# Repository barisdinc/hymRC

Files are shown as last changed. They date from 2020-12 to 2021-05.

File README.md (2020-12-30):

Bu projenin amaci role olarak kullanilmak uzere hazirlanan duzeneklerin kontrolunu saglamak ve bu sistemin uzaktan kumandasi ile tanitim bilgilerini olusturacak bir kart tasarimi yapmaktir.

Bu proje **_TA7OM Hudaverdi Gunes_**'in tesviki ile baslatilmistir. Mevcutta yillar once yaptigimiz ve pek cok rolede kullanilan genelde PIC tabanli Role Kontrol kartlarinin daha modern hale getirilmesi hedeflenecektir.

Aklimizdaki ozellikler asagidaki gibidir;

### Temel Ozellikler
1. Islemci unitesi olarak PIC yerine kolay erisilebilir ve programlanabilir ATMEL (Arduino) tercih edilecektir
1. 12 Volt ile beslenecektir
1. Role kontrol ozellikleri olacaktir
1. Durum gosterimi icin LED bulunacaktir
1. Dis arayuz baglantilari optokupler veya roleler uzerinden yapilacaktir
1. COR/CAS destegi olmalidir
1. COR/CAS destegi +/- olabilmelidir
1. Ayarlarin gosterimi icin LCD bulunacaktir (opsiyonel)
1. Ayarlarin goruntulenmesi/degistirilmesi icin rotary encoder bulunacaktir (opsiyonel)
1. Sistem icinde gercek zaman saati bulunacaktir (opsiyonel)
1. Roleye simplex Link sistemi ilave edilebilmelidir
  * Link COR girişi olmalı
  * Ancak Link girişinden sinyal geldiğinde Role de Kuyruk süresi olmamalı
  * İki VHF cihaz ile yapılan Role bir birine UHF üzerinden ücüncü cihaz ile Linkli olsun. 
  * iki cihazdan yapılan VHF Role Normal aktivtesini sürdürürken Kullanıcı Mandalı attığında Role göndermede iken aynı zamanda UHF link cihazı da göndermeye geçmelidir. 
  * Kullanıcı Mandalı bıraktığında Role Kuruk süresi sonrasında kapanacak ancak Link ise hiçbir gecikme olmadan, yani kuyruk süresi olmadan anında kapanacak. Bunun amacı Link üzerinden gelen sinyal zaten bir rokleden gelmekte olup, üzerinde kuyruk süresi vardır. 
  * ikinci bir kuyruk süresine ihtiyaç yoktur.
1. ...

### Role KOntrol Ozellikleri
1. Squelch/Sinyal girisi
1. Otomatik enterferans engelleme
1. ... 

### Uzaktan Kumanda Ozellikleri
1. DTMF ile uzaktan kumanda ozelligi olacaktir
1. Role acma/kapatma
1. Ton acma/kapatma
1. Morse tanitim acma/kapatma
1. AX25 tanitim acma/kapatma
1. belirlenen sure boyunca kapali kalma
1. Otomatik enterferans engelleme acma/kapama
1. Link acma/kapama
1. Kuyruk suresi ayari (uzun/orta/kisa)
1. Fan/Role acma/kapatma
1. AX25 ile uzaktan ayar yuklenmesi yapilabilecektir (opsiyonel)
1. SSTV Goruntusu iste (opsiyonel)
1. ...

### Tanitim Bilgisi
1. Beacon Tanitim ozelligi bulunacaktir (Orn: YM7KO 88.5 KN80WU 5W -10C 138V 121220 1919)
  * Morse olarak istasyon tanitimi basacaktir
  * Morse tanitim icinde asagidaki bilgiler olacaktir
  * Ton bilgisi
  * Lokasyon bilgisi (grid   square)
  * Cikis Gucu
  * Ortam sicakligi
  * Aku voltajlari
  * Tarih ve saat (gercek zamani opsiyonu durumunda
  * ...
  
1. Uzaktan kumanda sifre kontrollu olacaktir
  * Sifre uzaktan degistirilebilecektir
  * Sifre tanimli bir sifre kumesinden (Orn: 10 degisik sifre) sirayla degisecektir, aktif sifre no sorgulanabilecektir
  * ...
  
1. Beacon sinyali AX25 olarak da gonderilecektir
  * AX25 beacon sinyali icinde rolenin tum ayarlarinin aktif durumu bulunabilecektir
  * ...

**NOT:** Liste ilgili goruslerinizi ve eklenmesini istediginiz ozellikleri ISSUE bolumunden veya email ile bize bildiriniz. (barisdinc###gmail.com)

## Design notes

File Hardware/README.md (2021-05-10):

This folder will contain Schematic and PCB versions for different repeater application options

PCBs arrived...
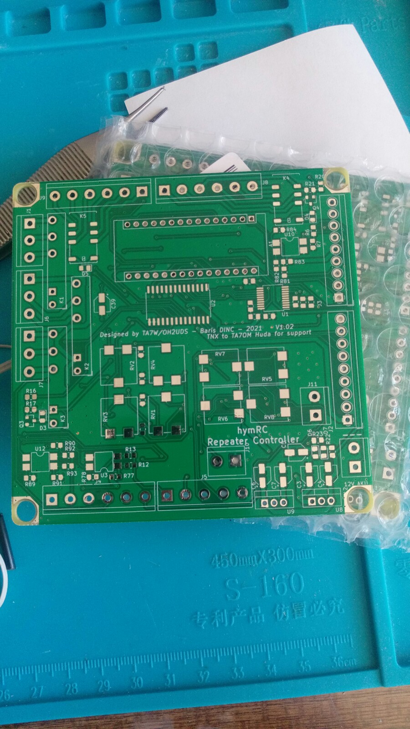
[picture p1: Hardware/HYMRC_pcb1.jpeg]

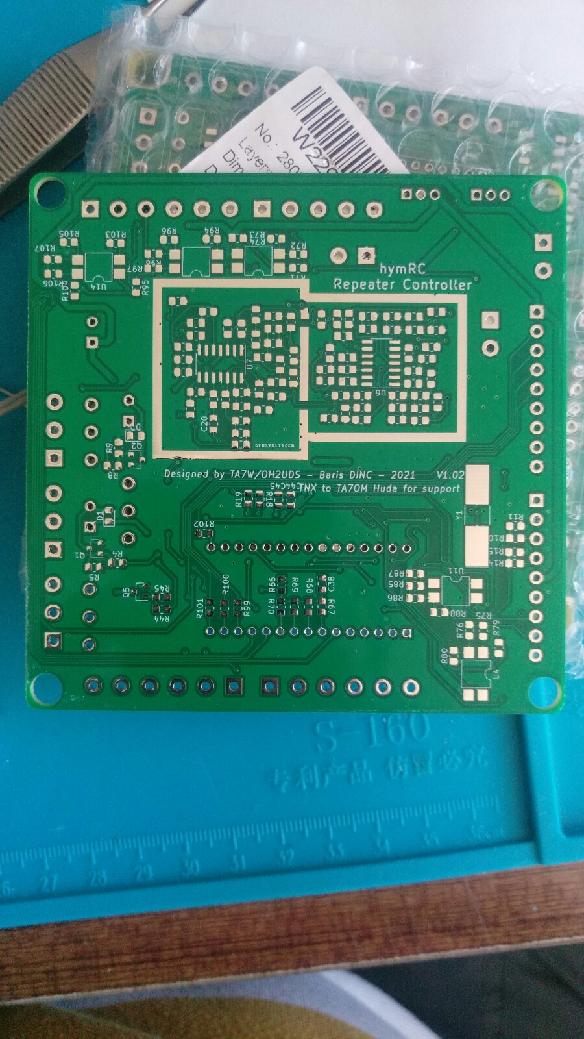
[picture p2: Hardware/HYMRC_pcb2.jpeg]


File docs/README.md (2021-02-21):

Atmega328p uzerinde 14 adet digital ve 8 adet analog pine sahiptir. BU pinlerden bazilari ozel amaclar icin peripherallere baglidir (Orn: seri, I2C, SPI veya PWM)

# Pin eslemeleri :
## Digital pinler
### Seri Data
Role kontrolcusunu ilerde baska bir sistemler bhaberlestirme ihtiyaci dogrudugune bu pinler seri haberlesme amaciyla kullanilacaktir
* D0 Seri iletisim icin kullanilacak (RX)
* D1 Seri iletisim icin kullanilacak (TX)

### interrupt (kesme) gerektiren islemler icin
* D2 KS8870 StD (interrupt)
* D3 Squelch input icin interrupt (ya da daha hizli bir is icin)

###TOne Decoder baglantisi (4+1 Pin)

* D4 MT8870 Q1
* D5 MT8870 Q2
* D6 MT8870 Q3
* D7 MT8870 Q4

### Mors ve data uretme
* ???? PWM cikisi olarak kullanialcak

### Acma kapama isleri
* D8 PTT kontrol
* D9 Role veya Digital  KOntrol 1

### Harici veriyolu (sensorler vb icin SPI)
* D10 SPI ihtiyaci icin kullanialcak (SS)
* D11 SPI ihtiyaci icin kullanialcak (MOSI)
* D12 SPI ihtiyaci icin kullanialcak (MISO)
* D13 SPI ihtiyaci icin kullanialcak (SCK)

## Analog Okuyucular
### Algilayicilar
* A0 Aku Durumu
* A1 Analog Sensor 1 (ornek: sicaklik, isik durumu, ruzgar)
* A2 Analog Sensor 2 (ornek: sicaklik, isik durumu, ruzgar)

* A3 BOS (AX25 dinleme icin kullanilabilir)

### Harici veriyolu (sensorler vb icin I2C)
* A4 I2C iletisim icin kullanilacak (SDA)
* A5 I2C iletisim icin kullanilacak (SCL)

* A6 BOS
* A7 BOS

Onemli Not:
-----------
* Rolenin mors ciktisina ek olarak AX25 paket radyo verisi olusturmak icin en az 4 pin ayristirilmasi gerekebilir ya da harici bir DAC chip kullanilabilir
* Rolenin AX25 alma islemi yapabilmesi icin analog portlardan birinin bu ise ayrilmasi gerekebilir

### Test Devresi
## MT3170 / KT8870 Bacak Baglantilari
Piyasada en kolay bulunan versiyonu 18 bacakli hali olup eger benim gibi kazara 20 bacakli versiyonunu kullaniyorsaniz internette cok kolay bulunamayan bacak baglanti detaylari asagidaki gibidir;

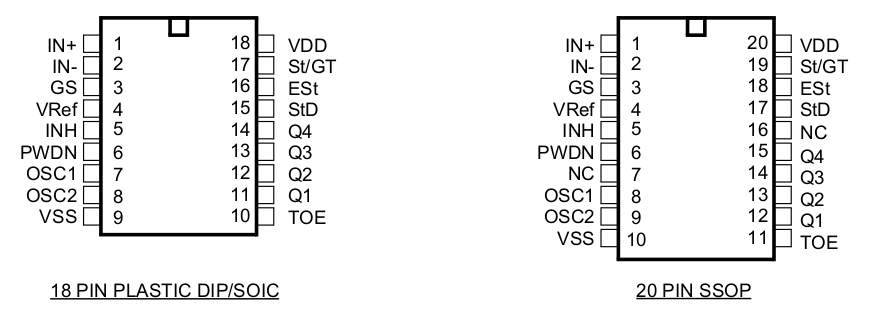
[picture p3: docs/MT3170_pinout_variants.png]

  
Ilk ornek uygulamamda asagidaki gibi bir devreyi kucuk bir protoboard uzerine kurup calismaya basladim;
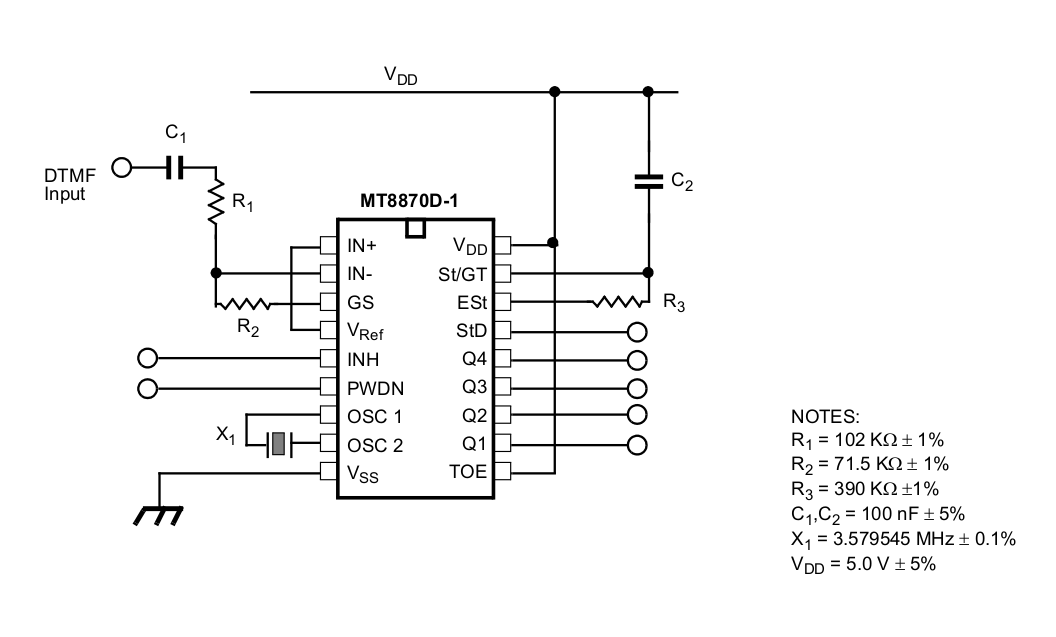
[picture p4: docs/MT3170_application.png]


Kurulu hali gorunumu

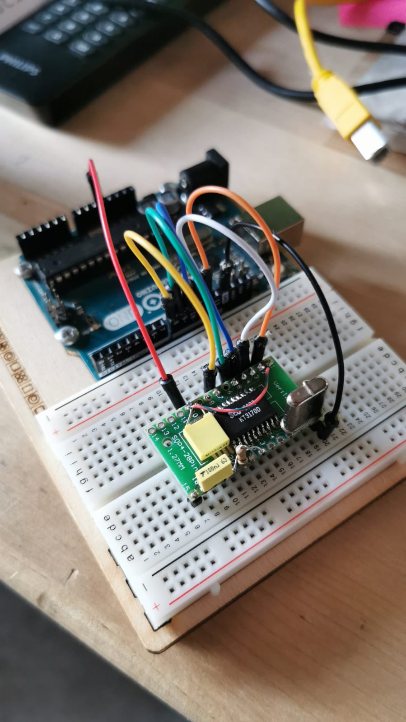
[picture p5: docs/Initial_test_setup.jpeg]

  
## 16 Bit port genisletici kullanimi
 
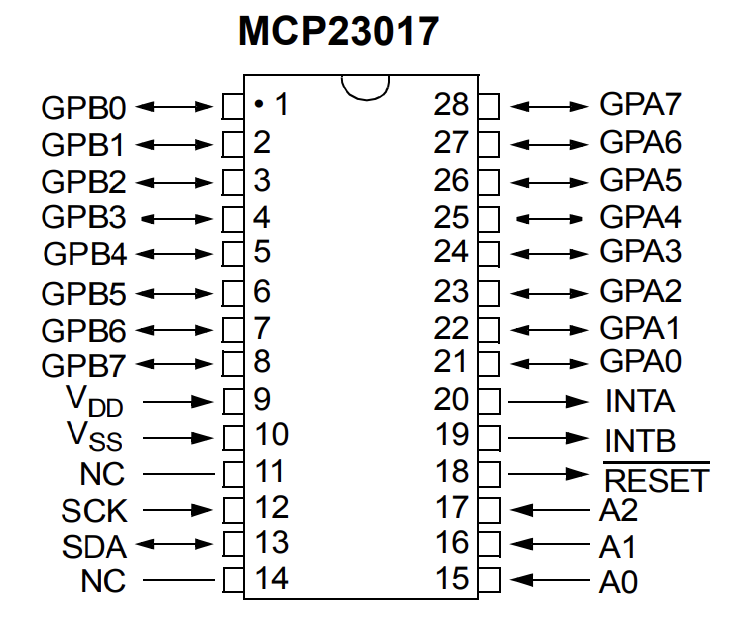
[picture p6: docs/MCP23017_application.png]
 
  
 * A0
 * A1
 * A2
 * A3
 * A4
 * A5
 * A6
 * A7
 * A8
  
 * B0 MT8870 Q1       (input) Interrupt On Pin
 * B1 MT8870 Q2       (input) Interrupt On Pin
 * B2 MT8870 Q3       (input) Interrupt On Pin
 * B3 MT8870 Q4       (input) Interrupt On Pin
 * B4 MT8870 StD      (input) Interrupt On Change 
 * B5 General Purpose (input) No Interrupt
 * B6 General Purpose (input) No Interrupt
 * B7 General Purpose (input) No Interrupt
  
 * INTA -> Pin 2 of MCU (INT0)
 * INTB -> Pin 3 of MCU (INT1)

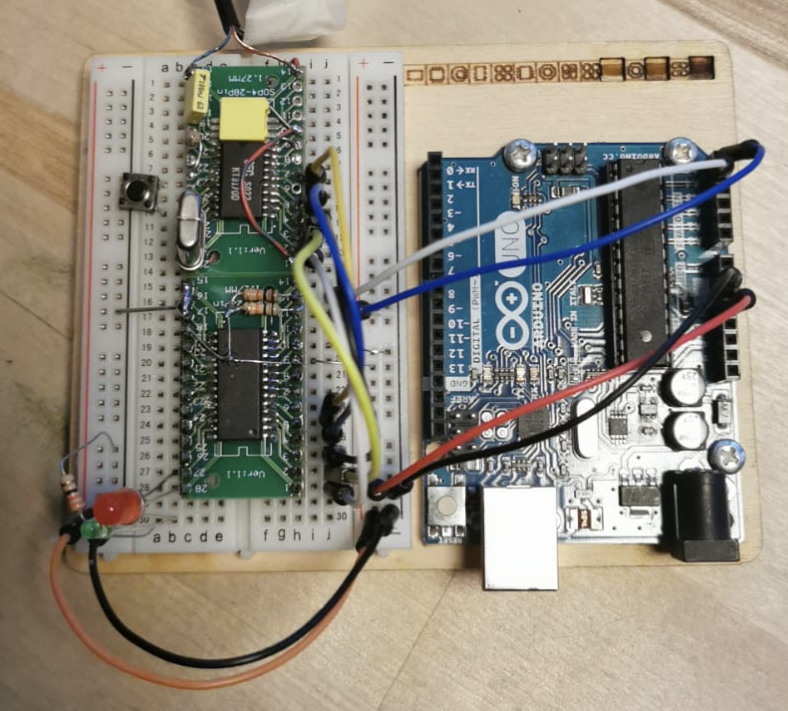
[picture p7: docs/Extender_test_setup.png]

  
## Initial Version Of Schematic
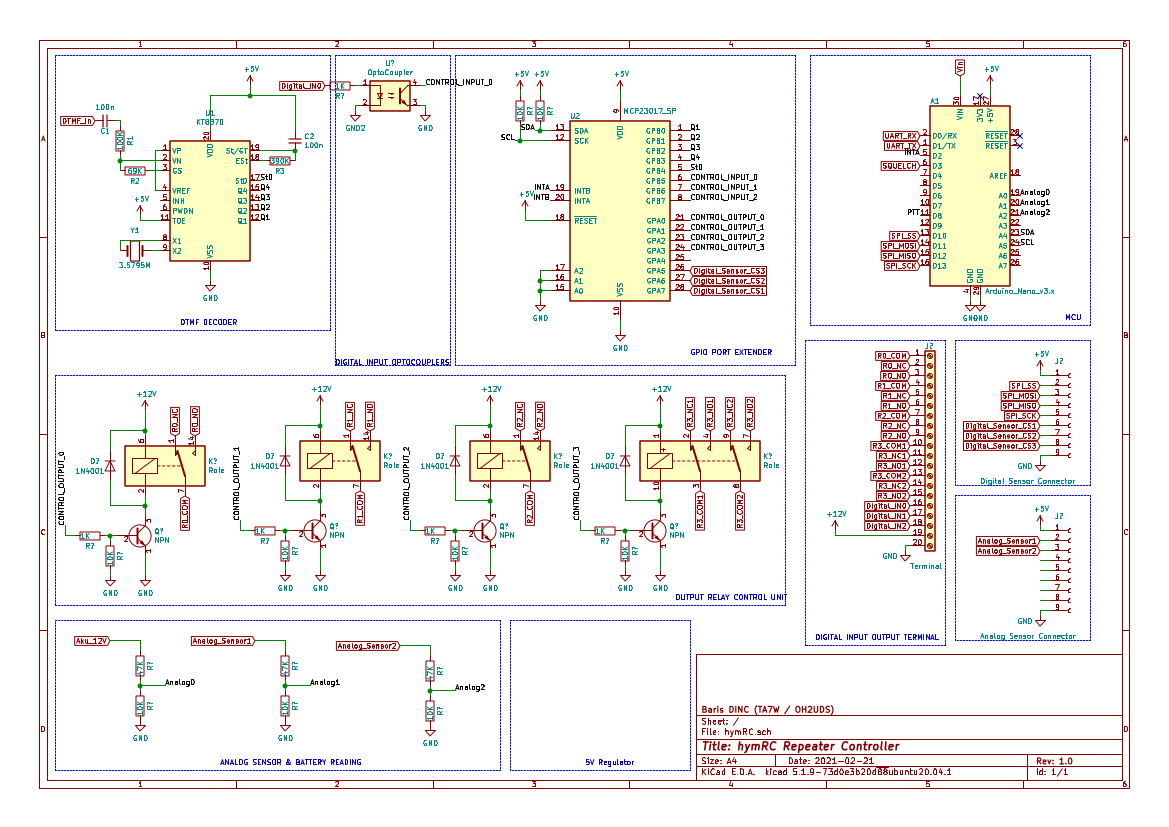
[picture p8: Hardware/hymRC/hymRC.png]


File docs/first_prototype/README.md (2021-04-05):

this is first prototype 3D views of KiCAD files....

#Front View:
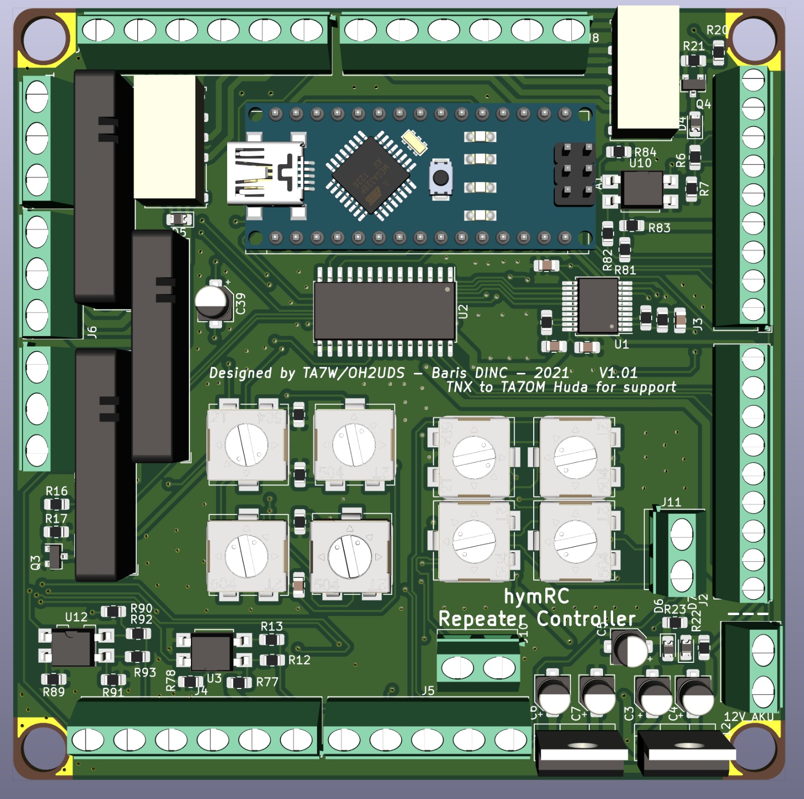
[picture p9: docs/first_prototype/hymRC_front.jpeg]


#Back View:
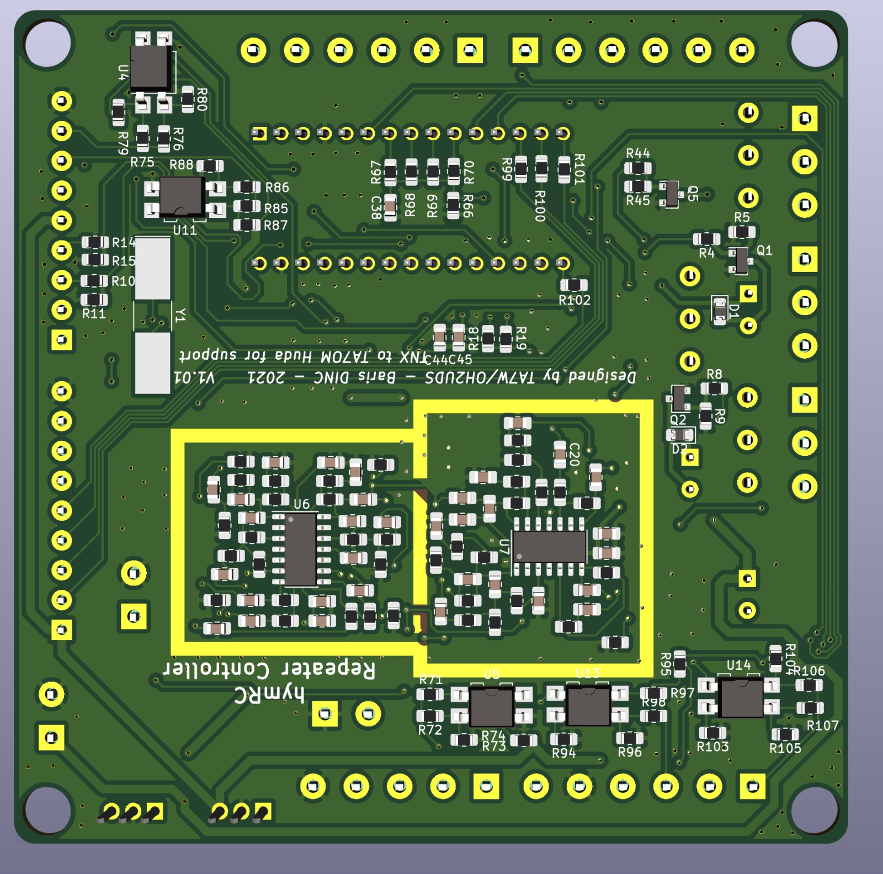
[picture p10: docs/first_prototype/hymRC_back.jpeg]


#Angle View:
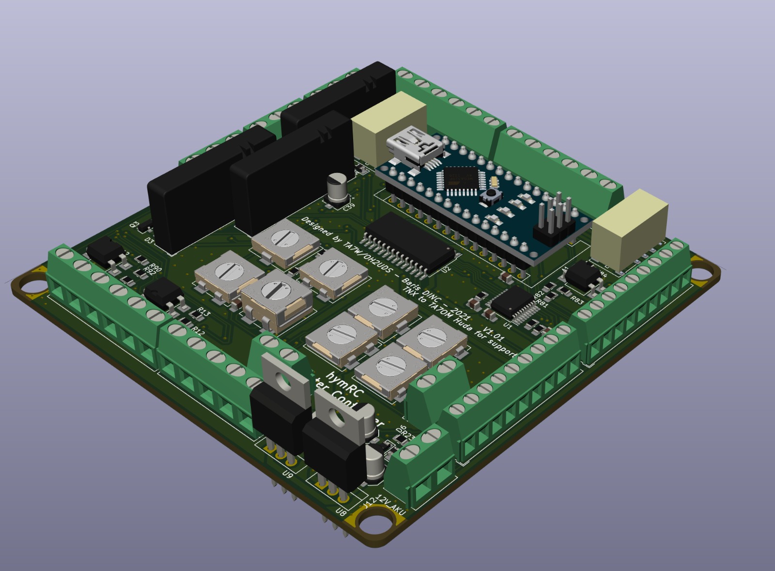
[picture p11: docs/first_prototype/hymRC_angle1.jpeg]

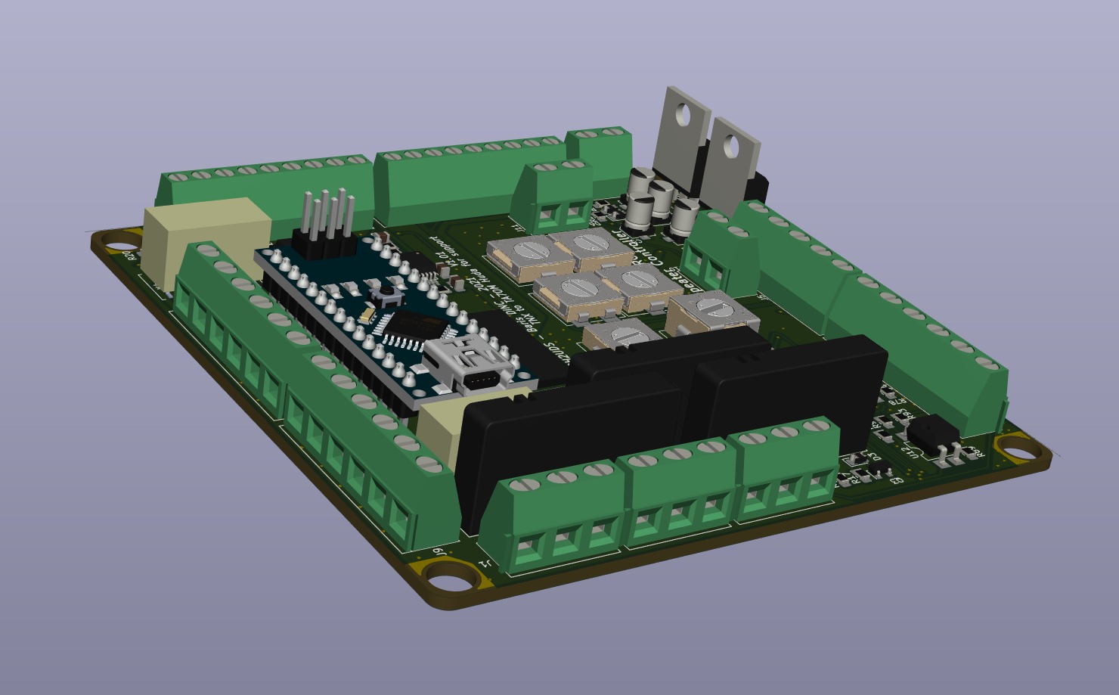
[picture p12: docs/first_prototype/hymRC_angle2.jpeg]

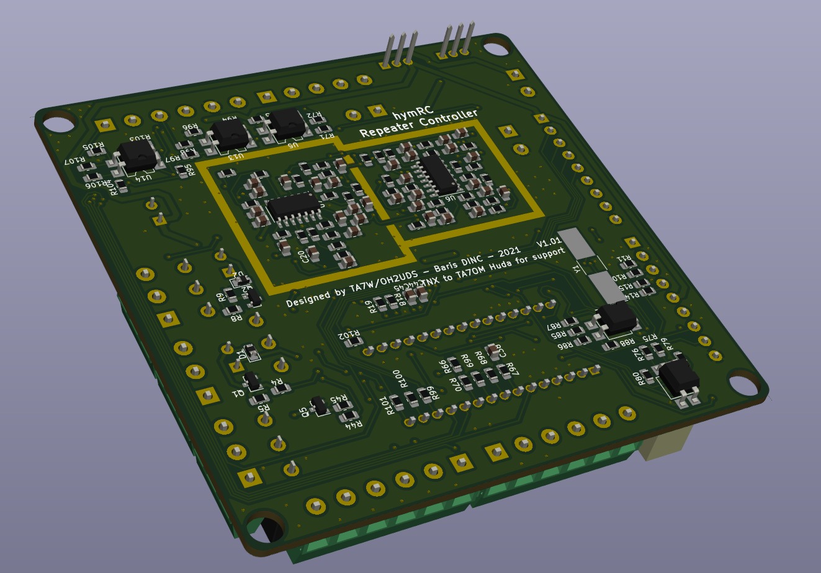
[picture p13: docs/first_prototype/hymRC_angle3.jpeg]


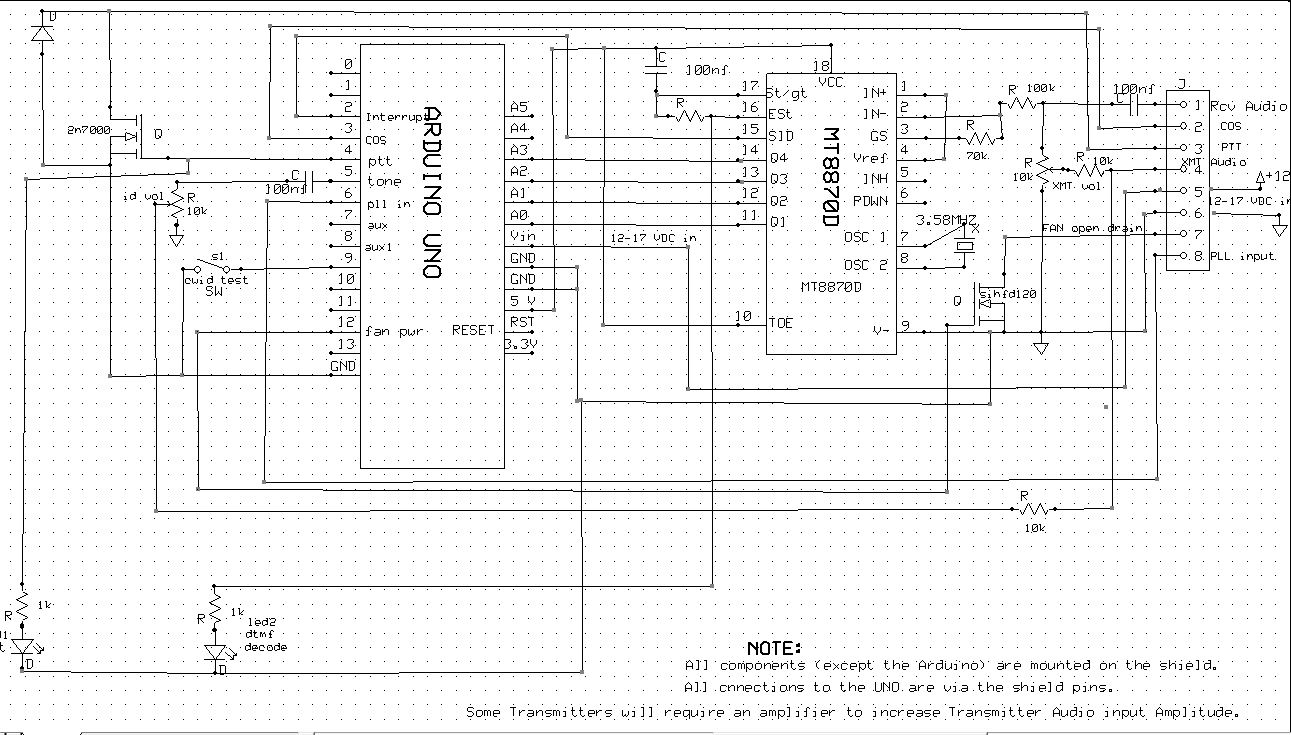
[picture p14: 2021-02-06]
Research/Rpt w_DTMF schematic.JPG

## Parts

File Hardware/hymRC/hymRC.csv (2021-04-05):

Id | Designator | Package | Quantity | Designation | Supplier and ref
1 | Y1 | Crystal_SMD_SeikoEpson_MC405-2Pin_9.6x4.1mm_HandSoldering | 1 | 3.5795M
2 | U14,U13,U12,U11,U10,U5,U4,U3 | SMDIP-4_W7.62mm | 8 | OptoCoupler
3 | U9 | TO-220-3_Vertical | 1 | L7805
4 | U8 | TO-220-3_Vertical | 1 | LM7808_TO220
5 | U7,U6 | SOIC-14_3.9x8.7mm_P1.27mm | 2 | TL084
6 | U2 | SOIC-28W_7.5x17.9mm_P1.27mm | 1 | MCP23017_SP
7 | U1 | SSOP-20_5.3x7.2mm_P0.65mm | 1 | KT8870
8 | RV8,RV7,RV6,RV5,RV4,RV3,RV2,RV1 | Potentiometer_ACP_CA9-VSMD_Vertical | 8 | 10K
9 | R107,R106,R105,R98,R97,R96,R93,R92,R91 | R_0805_2012Metric_Pad1.20x1.40mm_HandSolder | 9 | 0
10 | R104,R103,R95,R94,R90,R89,R85,R81,R75,R71,R66,R12 | R_0805_2012Metric_Pad1.20x1.40mm_HandSolder | 12 | 270
11 | R102,R101,R100,R99 | R_0805_2012Metric_Pad1.20x1.40mm_HandSolder | 4 | 27
12 | R88,R87,R86,R84,R83,R82,R80,R79,R78,R77,R76,R74,R73,R72,R13 | R_0805_2012Metric_Pad1.20x1.40mm_HandSolder | 15 | DNP
13 | R70,R44,R20,R16,R8,R4 | R_0805_2012Metric_Pad1.20x1.40mm_HandSolder | 6 | 1K
14 | R69 | R_0805_2012Metric_Pad1.20x1.40mm_HandSolder | 1 | 2K2
15 | R68 | R_0805_2012Metric_Pad1.20x1.40mm_HandSolder | 1 | 3K3
16 | R67 | R_0805_2012Metric_Pad1.20x1.40mm_HandSolder | 1 | 8K8
17 | R65,R64,R43,R35 | R_0805_2012Metric_Pad1.20x1.40mm_HandSolder | 4 | 1M2
18 | R63,R62,R53,R52,R49,R48,R47,R46,R42,R37,R34,R33,R32,R27,R25,R24,R1 | R_0805_2012Metric_Pad1.20x1.40mm_HandSolder | 17 | 100K
19 | R61,R60,R41,R40 | R_0805_2012Metric_Pad1.20x1.40mm_HandSolder | 4 | 4K7
20 | R59,R31 | R_0805_2012Metric_Pad1.20x1.40mm_HandSolder | 2 | 12K
21 | R58,R30 | R_0805_2012Metric_Pad1.20x1.40mm_HandSolder | 2 | 11K
22 | R57,R55,R39,R29 | R_0805_2012Metric_Pad1.20x1.40mm_HandSolder | 4 | 18K
23 | R56,R54,R45,R38,R28,R21,R19,R18,R17,R15,R11,R9,R7,R5 | R_0805_2012Metric_Pad1.20x1.40mm_HandSolder | 14 | 10K
24 | R51,R50,R36,R26 | R_0805_2012Metric_Pad1.20x1.40mm_HandSolder | 4 | 1M
25 | R23,R22 | R_0805_2012Metric_Pad1.20x1.40mm_HandSolder | 2 | 1K3
26 | R14,R10,R6 | R_0805_2012Metric_Pad1.20x1.40mm_HandSolder | 3 | 47K
27 | R3 | R_0805_2012Metric_Pad1.20x1.40mm_HandSolder | 1 | 390K
28 | R2 | R_0805_2012Metric_Pad1.20x1.40mm_HandSolder | 1 | 69K
29 | Q5,Q4,Q3,Q2 | SOT-23 | 4 | NPN
30 | Q1 | SOT-23 | 1 | BC817
31 | K5,K4 | Relay_DPDT_Kemet_EE2_NUH | 2 | Role
32 | K3,K2,K1 | Relay_SPDT_Finder_34.51_Vertical | 3 | Role
33 | J11 | TerminalBlock_bornier-2_P5.08mm | 1 | EXT_AUD_OUT
34 | J10 | TerminalBlock_bornier-2_P5.08mm | 1 | EXT_AUD_IN
35 | J9 | TerminalBlock_bornier-6_P5.08mm | 1 | Relay_4
36 | J8 | TerminalBlock_bornier-6_P5.08mm | 1 | Relay_3
37 | J7 | TerminalBlock_bornier-3_P5.08mm | 1 | Relay_2
38 | J6 | TerminalBlock_bornier-3_P5.08mm | 1 | Relay_1
39 | J5 | TerminalBlock_bornier-5_P5.08mm | 1 | RX RADIO
40 | J4 | TerminalBlock_bornier-6_P5.08mm | 1 | TX RADIO
41 | J3 | TerminalBlock_4Ucon_1x09_P3.50mm_Horizontal | 1 | Analog Sensor Connector
42 | J2 | TerminalBlock_4Ucon_1x09_P3.50mm_Horizontal | 1 | Digital Sensor Connector
43 | J1 | TerminalBlock_bornier-3_P5.08mm | 1 | Relay_0
44 | D7,D6 | D_0805_2012Metric_Pad1.15x1.40mm_HandSolder | 2 | 1N914
45 | D5,D4,D3,D2,D1 | D_0805_2012Metric_Pad1.15x1.40mm_HandSolder | 5 | 1N4001
46 | C47,C45,C41,C40 | C_0805_2012Metric_Pad1.18x1.45mm_HandSolder | 4 | 10nF
47 | C46,C44,C43,C42,C38 | C_0805_2012Metric_Pad1.18x1.45mm_HandSolder | 5 | 100nF
48 | C39,C7,C6,C5 | CP_Elec_4x5.8 | 4 | 10uF
49 | C37,C36,C35,C34,C33,C31,C22,C21,C20,C19,C14,C13 | C_0805_2012Metric_Pad1.18x1.45mm_HandSolder | 12 | 0.1uF
50 | C32,C12 | C_0805_2012Metric_Pad1.18x1.45mm_HandSolder | 2 | 0.0068uF
51 | C30,C29,C24,C23,C18,C15,C11,C8 | C_0805_2012Metric_Pad1.18x1.45mm_HandSolder | 8 | 0.22uF
52 | C28,C27,C26,C25,C17,C16,C10,C9 | C_0805_2012Metric_Pad1.18x1.45mm_HandSolder | 8 | 100pF
53 | C4,C3 | CP_Elec_4x5.8 | 2 | 1uF
54 | C2,C1 | C_0805_2012Metric_Pad1.18x1.45mm_HandSolder | 2 | 100n
55 | A1 | Arduino_Nano | 1 | Arduino_Nano_v3.x

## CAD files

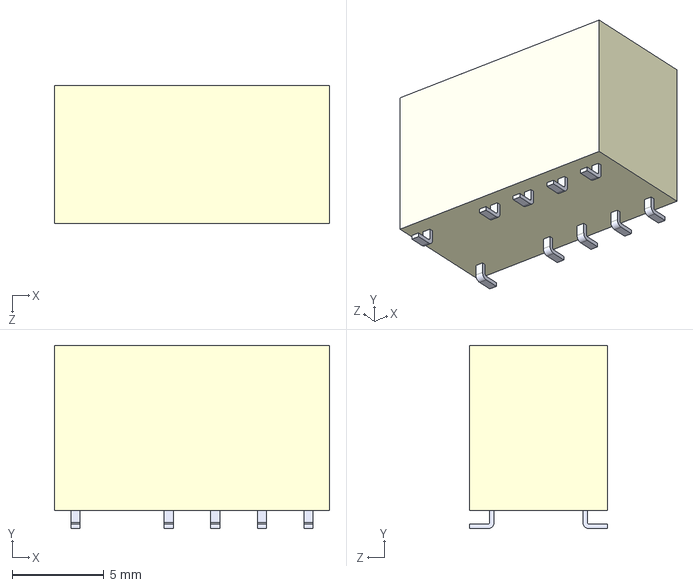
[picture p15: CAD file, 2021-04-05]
Hardware/hymRC/3D/EE2-3TNUH-L--3DModel-STEP-56544.STEP
15.0 x 10.0 x 7.50 mm

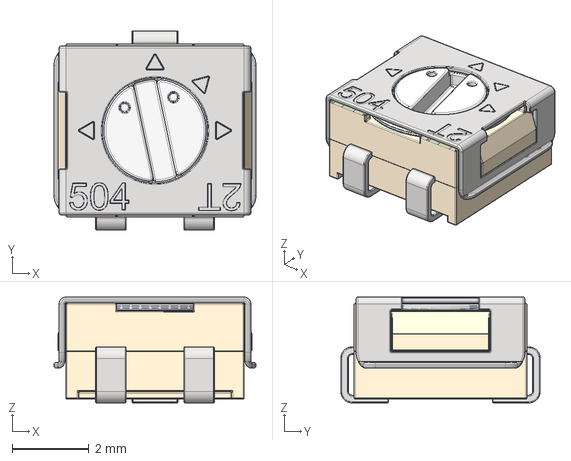
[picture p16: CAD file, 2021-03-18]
Hardware/hymRC/3D/Poti SMD 5k Bi Technologies 23AR5KLFTR.stp
5.27 x 5.20 x 2.76 mm

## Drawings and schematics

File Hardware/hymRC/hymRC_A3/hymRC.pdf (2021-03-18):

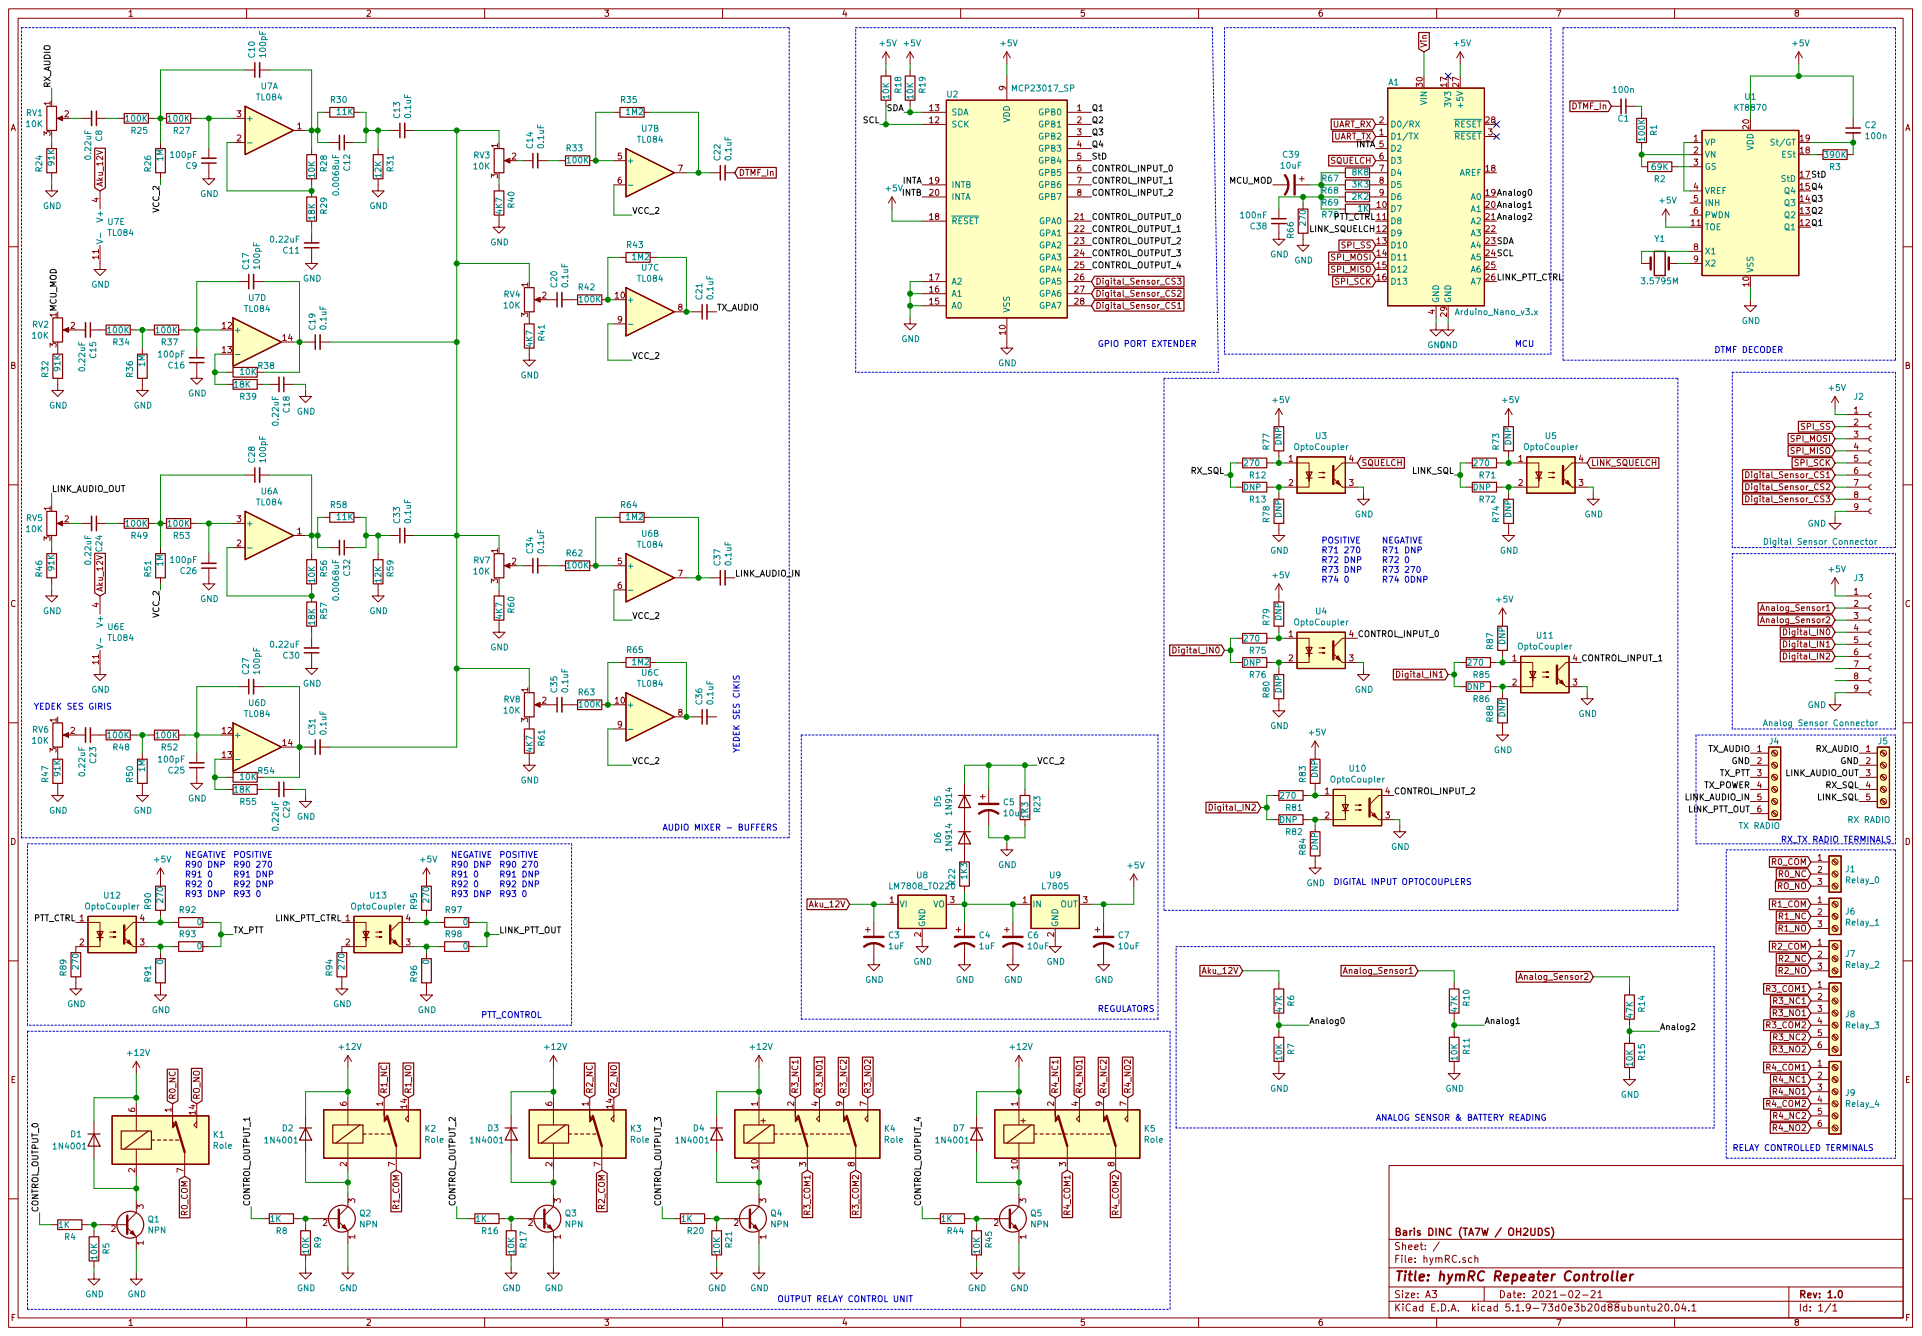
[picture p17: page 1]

J2 Digital Sensor Connector +5V GND

3 Q1 NPN C37 0.1uF GND GND C29 0.22uF GND GND

File: hymRC.sch Sheet: / Baris DINC (TA7W / OH2UDS) R59 12K

PTT_CONTROL

ANALOG SENSOR & BATTERY READING

Id: 1/1 Title: hymRC Repeater Controller

OUTPUT RELAY CONTROL UNIT

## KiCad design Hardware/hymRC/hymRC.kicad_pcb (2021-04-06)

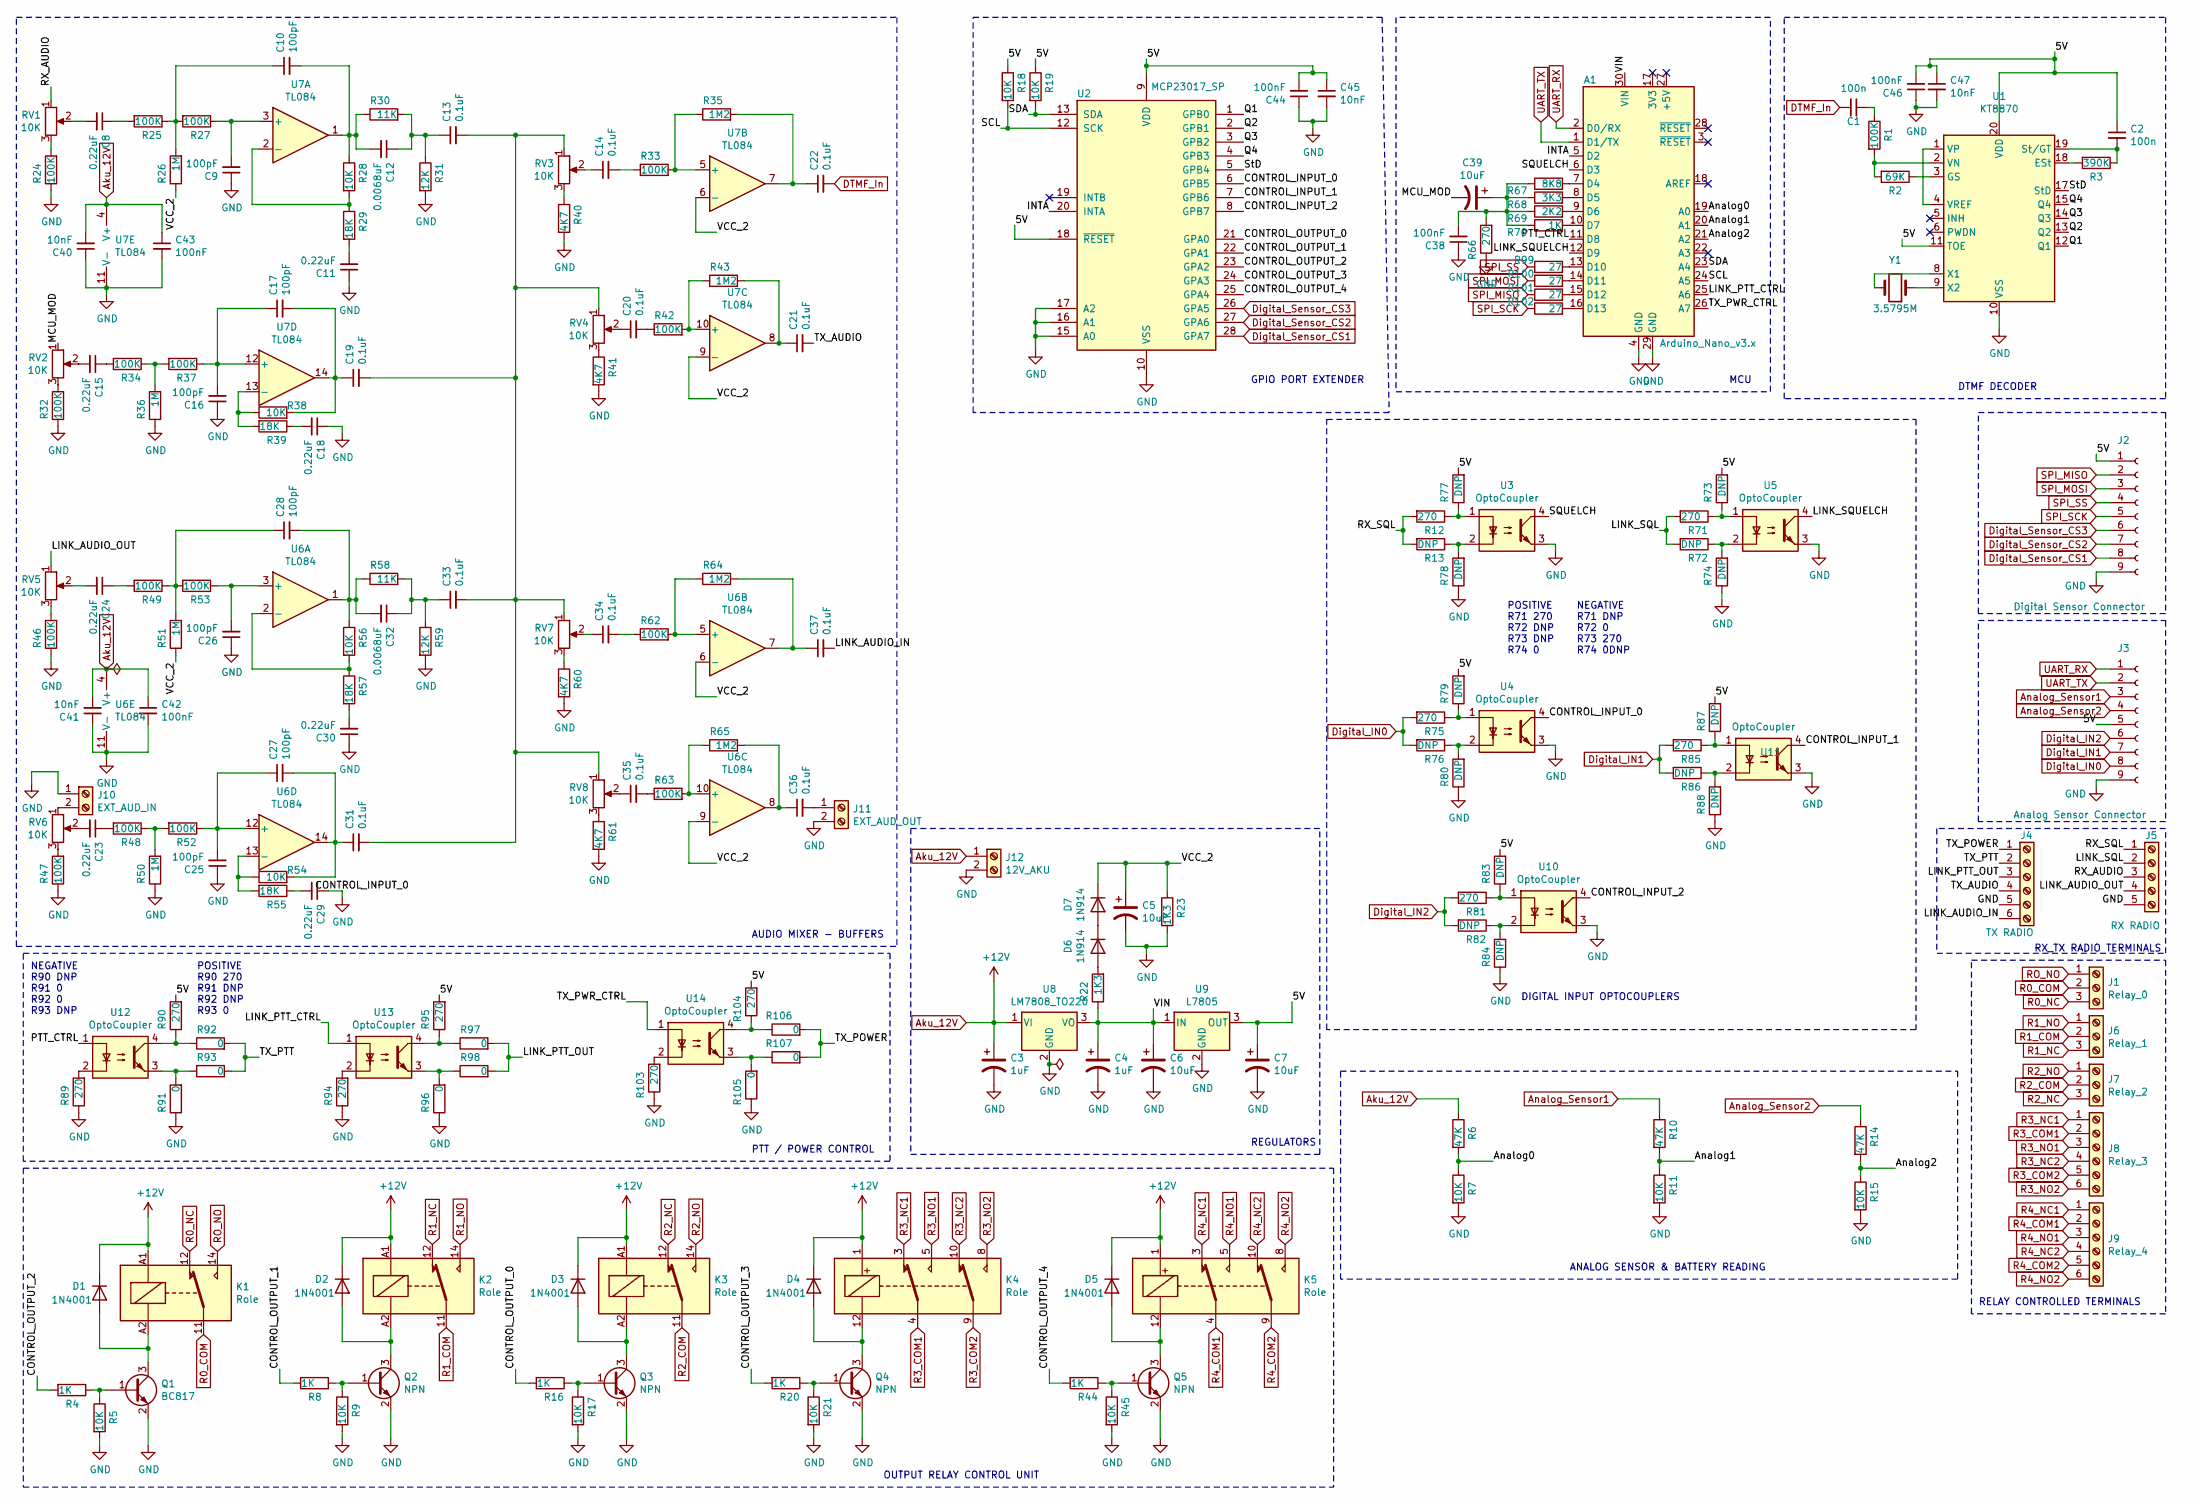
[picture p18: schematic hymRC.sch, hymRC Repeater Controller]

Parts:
A1: Arduino_Nano_v3.x; Arduino_Nano
C1, C2: 100n; C_0805_2012Metric_Pad1.18x1.45mm_HandSolder
C3, C4: 1uF; CP_Elec_4x5.8
C5, C6, C7, C39: 10uF; CP_Elec_4x5.8
C8, C11, C15, C18, C23, C24, C29, C30: 0.22uF; C_0805_2012Metric_Pad1.18x1.45mm_HandSolder
C9, C10, C16, C17, C25, C26, C27, C28: 100pF; C_0805_2012Metric_Pad1.18x1.45mm_HandSolder
C12, C32: 0.0068uF; C_0805_2012Metric_Pad1.18x1.45mm_HandSolder
C13, C14, C19, C20, C21, C22, C31, C33, C34, C35, C36, C37: 0.1uF; C_0805_2012Metric_Pad1.18x1.45mm_HandSolder
C38, C42, C43, C44, C46: 100nF; C_0805_2012Metric_Pad1.18x1.45mm_HandSolder
C40, C41, C45, C47: 10nF; C_0805_2012Metric_Pad1.18x1.45mm_HandSolder
D1, D2, D3, D4, D5: 1N4001; D_0805_2012Metric_Pad1.15x1.40mm_HandSolder
D6, D7: 1N914; D_0805_2012Metric_Pad1.15x1.40mm_HandSolder
J1: Relay_0; TerminalBlock_bornier-3_P5.08mm
J2: Digital Sensor Connector; TerminalBlock_4Ucon_1x09_P3.50mm_Horizontal
J3: Analog Sensor Connector; TerminalBlock_4Ucon_1x09_P3.50mm_Horizontal
J4: TX RADIO; TerminalBlock_bornier-6_P5.08mm
J5: RX RADIO; TerminalBlock_bornier-5_P5.08mm
J6: Relay_1; TerminalBlock_bornier-3_P5.08mm
J7: Relay_2; TerminalBlock_bornier-3_P5.08mm
J8: Relay_3; TerminalBlock_bornier-6_P5.08mm
J9: Relay_4; TerminalBlock_bornier-6_P5.08mm
J10: EXT_AUD_IN; TerminalBlock_bornier-2_P5.08mm
J11: EXT_AUD_OUT; TerminalBlock_bornier-2_P5.08mm
J12: 12V_AKU; TerminalBlock_bornier-2_P5.08mm
K1, K2, K3: Role; Relay_SPDT_Finder_34.51_Vertical
K4, K5: Role; Relay_DPDT_Kemet_EE2_NUH
Q1: BC817; SOT-23
Q2, Q3, Q4, Q5: NPN; SOT-23
R1, R24, R25, R27, R32, R33, R34, R37, R42, R46, R47, R48, R49, R52, R53, R62, R63: 100K; R_0805_2012Metric_Pad1.20x1.40mm_HandSolder
R2: 69K; R_0805_2012Metric_Pad1.20x1.40mm_HandSolder
R3: 390K; R_0805_2012Metric_Pad1.20x1.40mm_HandSolder
R4, R8, R16, R20, R44, R70: 1K; R_0805_2012Metric_Pad1.20x1.40mm_HandSolder
R5, R7, R9, R11, R15, R17, R18, R19, R21, R28, R38, R45, R54, R56: 10K; R_0805_2012Metric_Pad1.20x1.40mm_HandSolder
R6, R10, R14: 47K; R_0805_2012Metric_Pad1.20x1.40mm_HandSolder
R12, R66, R71, R75, R81, R85, R89, R90, R94, R95, R103, R104: 270; R_0805_2012Metric_Pad1.20x1.40mm_HandSolder
R13, R72, R73, R74, R76, R77, R78, R79, R80, R82, R83, R84, R86, R87, R88: DNP; R_0805_2012Metric_Pad1.20x1.40mm_HandSolder
R22, R23: 1K3; R_0805_2012Metric_Pad1.20x1.40mm_HandSolder
R26, R36, R50, R51: 1M; R_0805_2012Metric_Pad1.20x1.40mm_HandSolder
R29, R39, R55, R57: 18K; R_0805_2012Metric_Pad1.20x1.40mm_HandSolder
R30, R58: 11K; R_0805_2012Metric_Pad1.20x1.40mm_HandSolder
R31, R59: 12K; R_0805_2012Metric_Pad1.20x1.40mm_HandSolder
R35, R43, R64, R65: 1M2; R_0805_2012Metric_Pad1.20x1.40mm_HandSolder
R40, R41, R60, R61: 4K7; R_0805_2012Metric_Pad1.20x1.40mm_HandSolder
R67: 8K8; R_0805_2012Metric_Pad1.20x1.40mm_HandSolder
R68: 3K3; R_0805_2012Metric_Pad1.20x1.40mm_HandSolder
R69: 2K2; R_0805_2012Metric_Pad1.20x1.40mm_HandSolder
R91, R92, R93, R96, R97, R98, R105, R106, R107: 0; R_0805_2012Metric_Pad1.20x1.40mm_HandSolder
R99, R100, R101, R102: 27; R_0805_2012Metric_Pad1.20x1.40mm_HandSolder
RV1, RV2, RV3, RV4, RV5, RV6, RV7, RV8: 10K; Potentiometer_ACP_CA9-VSMD_Vertical
U1: KT8870; SSOP-20_5.3x7.2mm_P0.65mm
U2: MCP23017_SP; SOIC-28W_7.5x17.9mm_P1.27mm
U3, U4, U5, U10, U11, U12, U13, U14: OptoCoupler; SMDIP-4_W7.62mm
U6, U7: TL084; SOIC-14_3.9x8.7mm_P1.27mm
U8: LM7808_TO220; TO-220-3_Vertical
U9: L7805; TO-220-3_Vertical
Y1: 3.5795M; Crystal_SMD_SeikoEpson_MC405-2Pin_9.6x4.1mm_HandSoldering

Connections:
/5V: C2.1, C7.1, C44.2, C45.1, C46.2, C47.1, J2.1, J3.5, R18.1, R19.1, R73.2, R77.2, R79.2, R83.2, R87.2, R90.2, R95.2, R104.2, U1.11 (TOE), U1.20 (VDD), U2.9 (VDD), U2.18 (~RESET~), U9.3 (OUT)
/Analog0: A1.19 (A0), R6.2, R7.1
/Analog1: A1.20 (A1), R10.2, R11.1
/Analog2: A1.21 (A2), R14.2, R15.1
/CONTROL_INPUT_0: U2.6 (GPB5), U4.4
/CONTROL_INPUT_1: U2.7 (GPB6), U11.4
/CONTROL_INPUT_2: U2.8 (GPB7), U10.4
/CONTROL_OUTPUT_0: R16.2, U2.21 (GPA0)
/CONTROL_OUTPUT_1: R8.2, U2.22 (GPA1)
/CONTROL_OUTPUT_2: R4.2, U2.23 (GPA2)
/CONTROL_OUTPUT_3: R20.2, U2.24 (GPA3)
/CONTROL_OUTPUT_4: R44.2, U2.25 (GPA4)
/INTA: A1.5 (D2), U2.20 (INTA)
/LINK_AUDIO_IN: C37.2, J4.6
/LINK_AUDIO_OUT: J5.4, RV5.1
/LINK_PTT_CTRL: A1.25 (A6), U13.1
/LINK_PTT_OUT: J4.3, R97.2, R98.2
/LINK_SQL: J5.2, R71.2, R72.2
/LINK_SQUELCH: A1.12 (D9), U5.4
/MCU_MOD: C39.2, RV2.1
/PTT_CTRL: A1.11 (D8), U12.1
/Q1: U1.12 (Q1), U2.1 (GPB0)
/Q2: U1.13 (Q2), U2.2 (GPB1)
/Q3: U1.14 (Q3), U2.3 (GPB2)
/Q4: U1.15 (Q4), U2.4 (GPB3)
/RX_AUDIO: J5.3, RV1.1
/RX_SQL: J5.1, R12.2, R13.2
/SCL: A1.24 (A5), R18.2, U2.12 (SCK)
/SDA: A1.23 (A4), R19.2, U2.13 (SDA)
/SQUELCH: A1.6 (D3), U3.4
/StD: U1.17 (StD), U2.5 (GPB4)
/TX_AUDIO: C21.2, J4.4
/TX_POWER: J4.1, R106.2, R107.2
/TX_PTT: J4.2, R92.2, R93.2
/TX_PWR_CTRL: A1.26 (A7), U14.1
/VCC_2: C5.1, D7.1 (K), R23.1, R26.1, R51.1, U6.6 (-), U6.9 (-), U7.6 (-), U7.9 (-)
/VIN: A1.30 (VIN), C4.1, C6.1, R22.1, U8.3 (VO), U9.1 (IN)
Aku_12V: C3.1, C40.2, C41.2, C42.1, C43.1, D1.1 (K), D2.1 (K), D3.1 (K), D4.1 (K), D5.1 (K), J12.1, K1.A1, K2.A1, K3.A1, K4.1, K5.1, R6.1, U6.4 (V+), U7.4 (V+), U8.1 (VI)
Analog_Sensor1: J3.3, R10.1
Analog_Sensor2: J3.4, R14.1
DTMF_In: C1.2, C22.2
Digital_IN0: J3.8, R75.2, R76.2
Digital_IN1: J3.7, R85.2, R86.2
Digital_IN2: J3.6, R81.2, R82.2
Digital_Sensor_CS1: J2.8, U2.28 (GPA7)
Digital_Sensor_CS2: J2.7, U2.27 (GPA6)
Digital_Sensor_CS3: J2.6, U2.26 (GPA5)
GND: A1.4 (GND), A1.29 (GND), C3.2, C4.2, C5.2, C6.2, C7.2, C9.1, C11.1, C16.1, C18.1, C25.1, C26.1, C29.1, C30.1, C38.1, C40.1, C41.1, C42.2, C43.2, C44.1, C45.2, C46.1, C47.2, J2.9, J3.9, J4.5, J5.5, J10.1, J11.2, J12.2, Q1.2 (E), Q2.2 (E), Q3.2 (E), Q4.2 (E), Q5.2 (E), R5.2, R7.2, R9.2, R11.2, R15.2, R17.2, R21.2, R23.2, R24.1, R31.2, R32.1, R36.1, R40.2, R41.2, R45.2, R46.1, R47.1, R50.1, R59.2, R60.2, R61.2, R66.1, R74.1, R78.1, R80.1, R84.1, R88.1, R89.1, R91.1, R94.1, R96.1, R103.1, R105.1, U1.10 (VSS), U2.10 (VSS), U2.15 (A0), U2.16 (A1), U2.17 (A2), U3.3, U4.3, U5.3, U6.11 (V-), U7.11 (V-), U8.2 (GND), U9.2 (GND), U10.3, U11.3
unnamed: A1.7 (D4), R67.2
unnamed: A1.8 (D5), R68.2
unnamed: A1.9 (D6), R69.2
unnamed: A1.10 (D7), R70.2
unnamed: A1.13 (D10), R99.2
unnamed: A1.14 (D11), R100.2
unnamed: A1.15 (D12), R101.2
unnamed: A1.16 (D13), R102.2
unnamed: C1.1, R1.1
unnamed: C2.2, R3.1, U1.19 (St/GT)
unnamed: C8.1, R25.2
unnamed: C8.2, RV1.2
unnamed: C9.2, R27.1, U7.3 (+)
unnamed: C10.1, R25.1, R26.2, R27.2
unnamed: C10.2, C12.2, R28.1, R30.1, U7.1
unnamed: C11.2, R29.2
unnamed: C12.1, C13.1, R30.2, R31.1
unnamed: C13.2, C19.2, C31.2, C33.2, RV3.1, RV4.1, RV7.1, RV8.1
unnamed: C14.1, RV3.2
unnamed: C14.2, R33.1
unnamed: C15.1, R34.2
unnamed: C15.2, RV2.2
unnamed: C16.2, C17.1, R37.1, U7.12 (+)
unnamed: C17.2, C19.1, R38.2, U7.14
unnamed: C18.2, R39.1
unnamed: C20.1, RV4.2
unnamed: C20.2, R42.1
unnamed: C21.1, R43.2, U7.8
unnamed: C22.1, R35.2, U7.7
unnamed: C23.1, R48.2
unnamed: C23.2, RV6.2
unnamed: C24.1, R49.2
unnamed: C24.2, RV5.2
unnamed: C25.2, C27.1, R52.1, U6.12 (+)
unnamed: C26.2, R53.1, U6.3 (+)
unnamed: C27.2, C31.1, R54.2, U6.14
unnamed: C28.1, R49.1, R51.2, R53.2
unnamed: C28.2, C32.2, R56.1, R58.1, U6.1
unnamed: C29.2, R55.1
unnamed: C30.2, R57.2
unnamed: C32.1, C33.1, R58.2, R59.1
unnamed: C34.1, RV7.2
unnamed: C34.2, R62.1
unnamed: C35.1, RV8.2
unnamed: C35.2, R63.1
unnamed: C36.1, R65.2, U6.8
unnamed: C36.2, J11.1
unnamed: C37.1, R64.2, U6.7
unnamed: C38.2, C39.1, R66.2, R67.1, R68.1, R69.1, R70.1
unnamed: D1.2 (A), K1.A2, Q1.3 (C)
unnamed: D2.2 (A), K2.A2, Q2.3 (C)
unnamed: D3.2 (A), K3.A2, Q3.3 (C)
unnamed: D4.2 (A), K4.12, Q4.3 (C)
unnamed: D5.2 (A), K5.12, Q5.3 (C)
unnamed: D6.1 (K), D7.2 (A)
unnamed: D6.2 (A), R22.2
unnamed: J10.2, RV6.1
unnamed: Q1.1 (B), R4.1, R5.1
unnamed: Q2.1 (B), R8.1, R9.1
unnamed: Q3.1 (B), R16.1, R17.1
unnamed: Q4.1 (B), R20.1, R21.1
unnamed: Q5.1 (B), R44.1, R45.1
unnamed: R1.2, R2.2, U1.2 (VN)
unnamed: R2.1, U1.3 (GS)
unnamed: R3.2, U1.18 (ESt)
unnamed: R12.1, R77.1, U3.1
unnamed: R13.1, R78.2, U3.2
unnamed: R24.2, RV1.3
unnamed: R28.2, R29.1, U7.2 (-)
unnamed: R32.2, RV2.3
unnamed: R33.2, R35.1, U7.5 (+)
unnamed: R34.1, R36.2, R37.2
unnamed: R38.1, R39.2, U7.13 (-)
unnamed: R40.1, RV3.3
unnamed: R41.1, RV4.3
unnamed: R42.2, R43.1, U7.10 (+)
unnamed: R46.2, RV5.3
unnamed: R47.2, RV6.3
unnamed: R48.1, R50.2, R52.2
unnamed: R54.1, R55.2, U6.13 (-)
unnamed: R56.2, R57.1, U6.2 (-)
unnamed: R60.1, RV7.3
unnamed: R61.1, RV8.3
unnamed: R62.2, R64.1, U6.5 (+)
unnamed: R63.2, R65.1, U6.10 (+)
unnamed: R71.1, R73.1, U5.1
unnamed: R72.1, R74.2, U5.2
unnamed: R75.1, R79.1, U4.1
unnamed: R76.1, R80.2, U4.2
unnamed: R81.1, R83.1, U10.1
unnamed: R82.1, R84.2, U10.2
unnamed: R85.1, R87.1, U11.1
unnamed: R86.1, R88.2, U11.2
unnamed: R89.2, U12.2
unnamed: R90.1, R92.1, U12.4
unnamed: R91.2, R93.1, U12.3
unnamed: R94.2, U13.2
unnamed: R95.1, R97.1, U13.4
unnamed: R96.2, R98.1, U13.3
unnamed: R103.2, U14.2
unnamed: R104.1, R106.1, U14.4
unnamed: R105.2, R107.1, U14.3
unnamed: U1.1 (VP), U1.4 (VREF)
unnamed: U1.8 (X1), Y1.2
unnamed: U1.9 (X2), Y1.1
R0_COM: J1.2, K1.8, K1.11
R0_NC: J1.3, K1.12
R1_COM: J6.2, K2.8, K2.11
R1_NC: J6.3, K2.12
R1_NO: J6.1, K2.14
R2_COM: J7.2, K3.8, K3.11
R2_NC: J7.3, K3.12
R2_NO: J7.1, K3.14
R3_COM1: J8.2, K4.4
R3_COM2: J8.5, K4.9
R3_NC1: J8.1, K4.3
R3_NC2: J8.4, K4.10
R3_NO1: J8.3, K4.5
R3_NO2: J8.6, K4.8
R4_COM1: J9.2, K5.4
R4_COM2: J9.5, K5.9
R4_NC1: J9.1, K5.3
R4_NC2: J9.4, K5.10
R4_NO1: J9.3, K5.5
R4_NO2: J9.6, K5.8
RO_NO: J1.1, K1.14
SPI_MISO: J2.2, R101.1
SPI_MOSI: J2.3, R100.1
SPI_SCK: J2.5, R102.1
SPI_SS: J2.4, R99.1
UART_RX: A1.2 (D0/RX), J3.1
UART_TX: A1.1 (D1/TX), J3.2

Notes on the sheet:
DTMF DECODER
GPIO PORT EXTENDER
MCU
RELAY CONTROLLED TERMINALS
ANALOG SENSOR & BATTERY READING
REGULATORS
RX_TX RADIO TERMINALS
OUTPUT RELAY CONTROL UNIT
DIGITAL INPUT OPTOCOUPLERS
POSITIVE R71 270 R72 DNP R73 DNP R74 0
NEGATIVE R71 DNP R72 0 R73 270 R74 0DNP
AUDIO MIXER - BUFFERS
NEGATIVE R90 DNP R91 0 R92 0 R93 DNP
POSITIVE R90 270 R91 DNP R92 DNP R93 0
PTT / POWER CONTROL

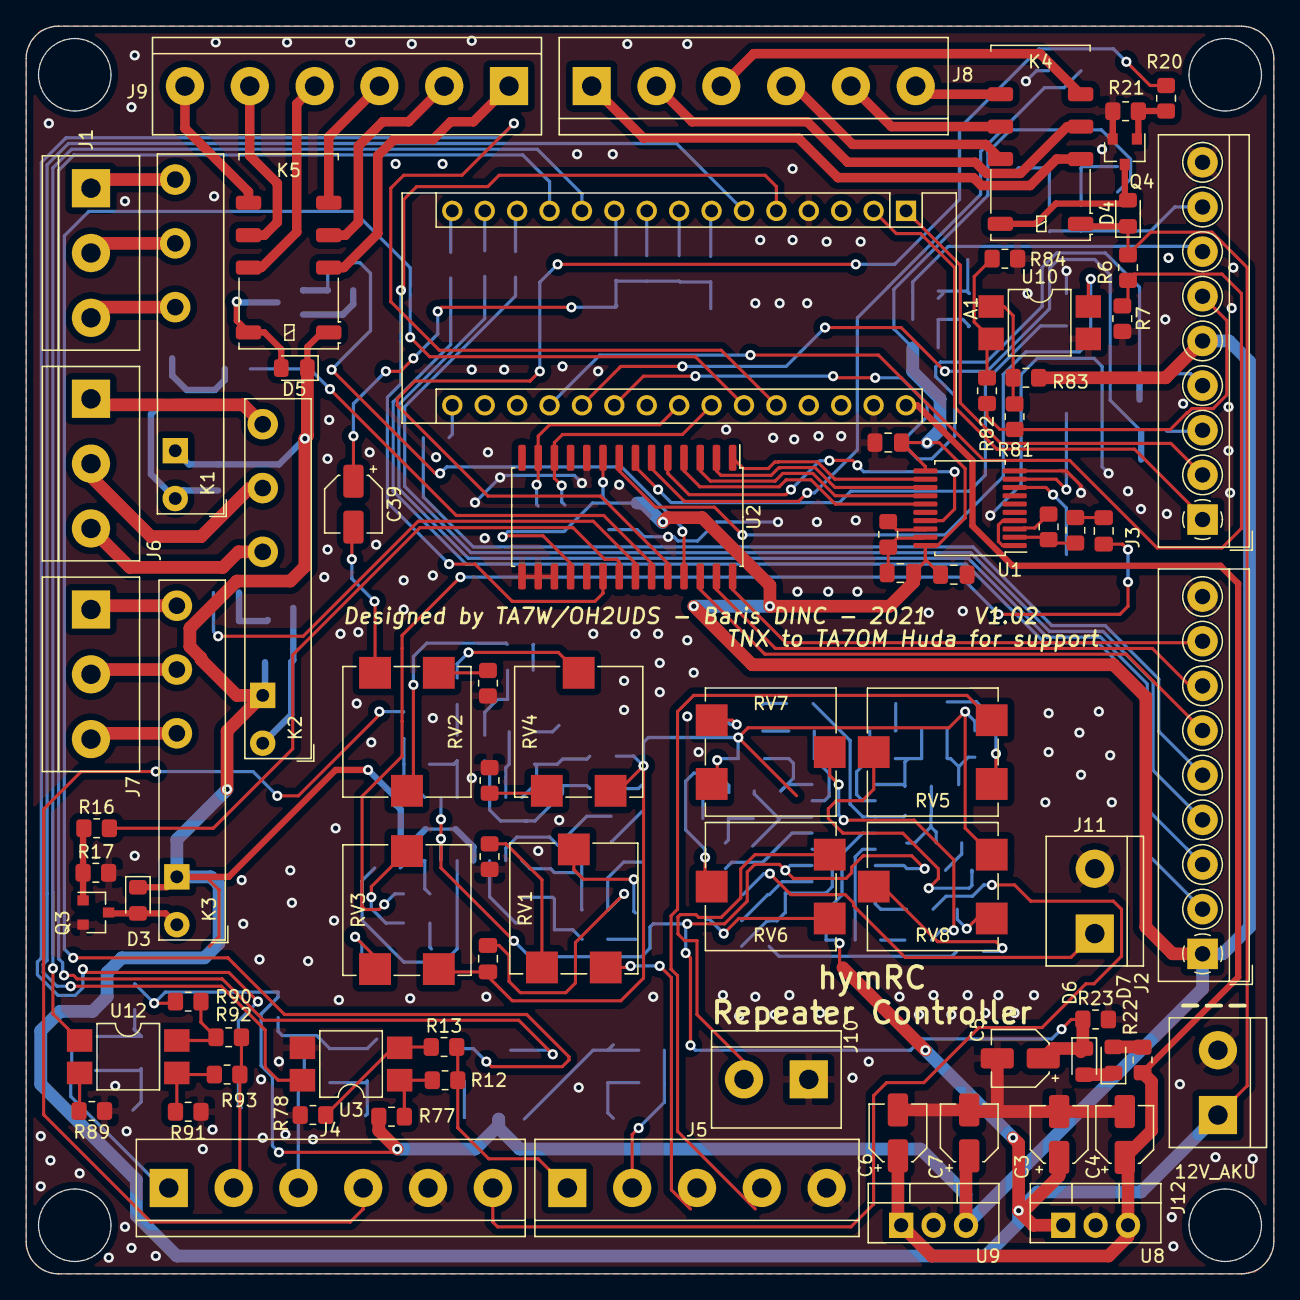
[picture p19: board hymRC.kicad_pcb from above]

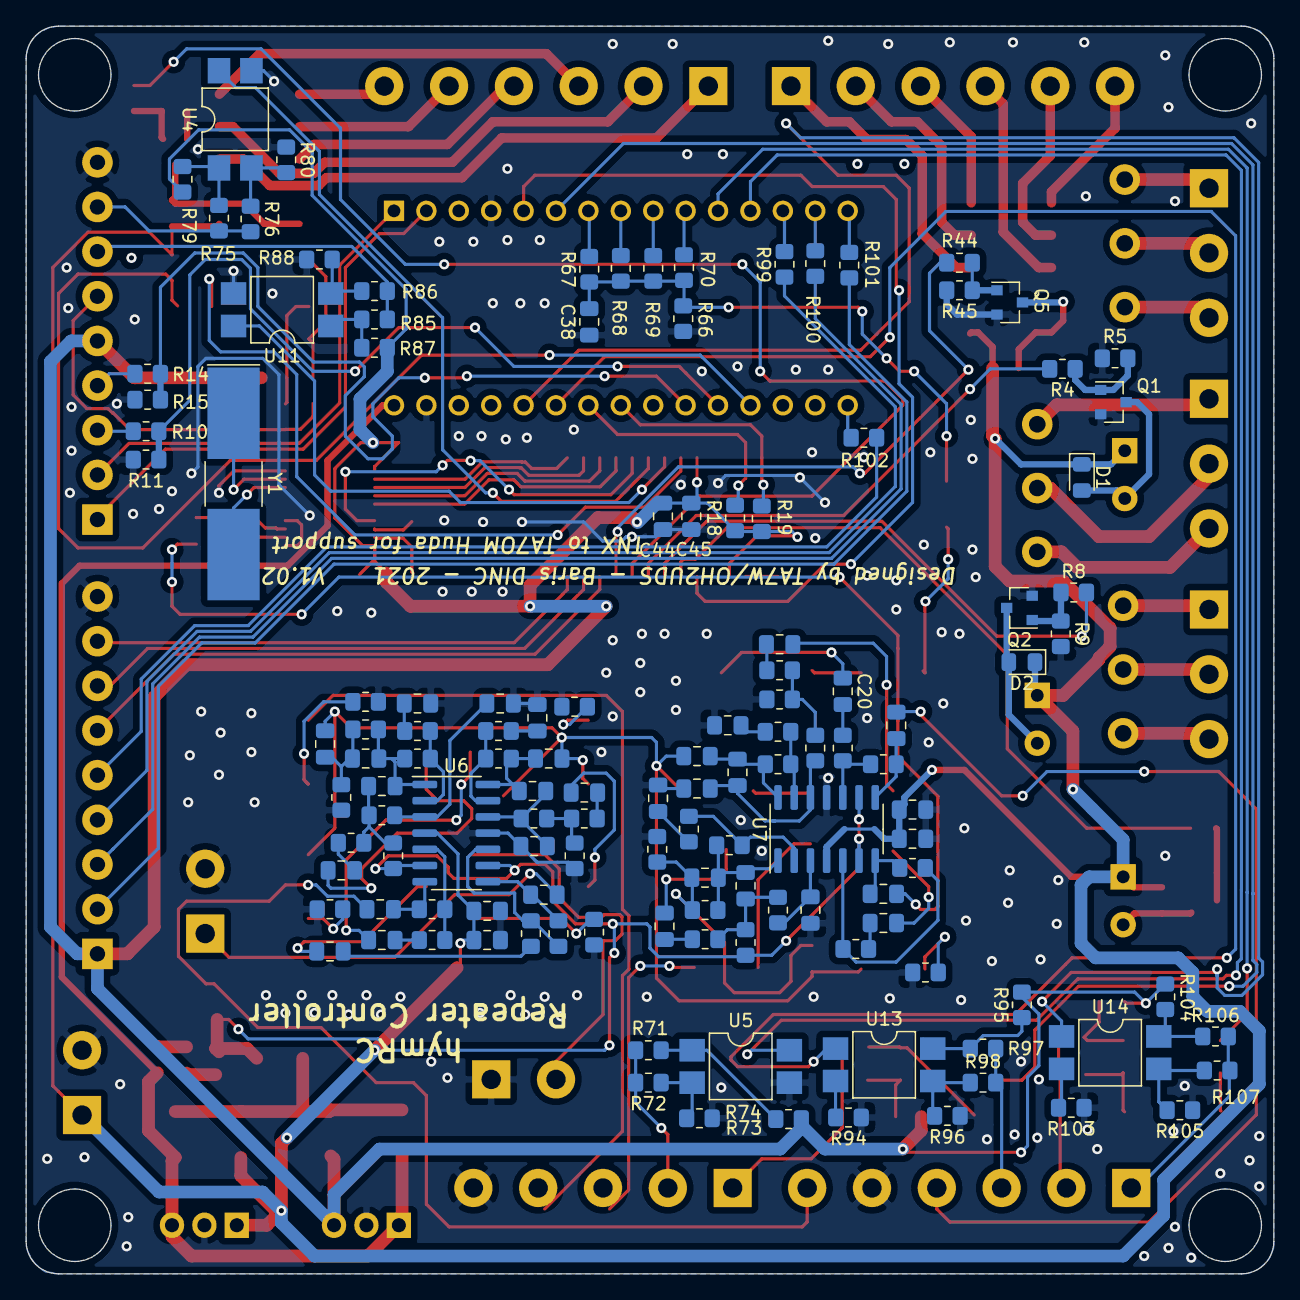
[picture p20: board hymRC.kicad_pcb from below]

Board: 2 copper layers, 97.8 x 97.8 mm, 207 parts (129 on the bottom side), 180 nets.

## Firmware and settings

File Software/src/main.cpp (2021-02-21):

#include <Arduino.h>
#include <EEPROMex.h>
#include <Wire.h>
#include "main.h"

/*
 DTMF Commands start with # and end with *
 After the # command all codes should be send within command_timeout_s seconds
 The maximum delay between digits can be maximum dtmf_timout_s seconds
 Every presence of # restarts the command sequence

 Command Structure is as follows (PPPP is required user/admin password)
 #PPPPCC*        Execute CC command 
 #PPPPSSVV*      Set SS variable value to VV 

 #PPPP71pppp*    Set user password to ppp
 #PPPP72pppp*    Set admin password to ppp
*/

volatile int interrupts;

uint8_t dtmf_cnt;
char dtmf_command[20];

Repeater_configutarion_t repeater_configuration;

unsigned long timer_stop_tx;  
unsigned long timer_command_timeout;
unsigned long timer_dtmf_timeout;
 
bool execute_cmd = false;
bool tx_state = false;


void setup() {
    noInterrupts();

    init_configuration(&repeater_configuration);

    //TCCR1A = 0; 
    //TCCR1B = 0;
    //TCNT1 = 15624; // 1Hz = 16.000.000 / (1024 * 1) - 1
    //TCCR1B |= (1 << CS12); //256 prescaler
    //TIMSK1 |= (1 << TOIE1); //Enable Timer Overflow Interrupt


    attachInterrupt(0, dtmf_interrupt, FALLING); //Interrupt0 is Pin D2, FAILING edge shows dtmf read is done
    attachInterrupt(1, squelch_interrupt, CHANGE); //Interrupt1 is Pin D3, CHANGE triggers state change
    pinMode(LED_BUILTIN, OUTPUT);
    pinMode(squelch_in_pin, INPUT_PULLUP);
    pinMode(ptt_pin, OUTPUT);

    pinMode(dtmf_pinSTD, INPUT);
    pinMode(dtmf_pinQ1, INPUT);
    pinMode(dtmf_pinQ2, INPUT);
    pinMode(dtmf_pinQ3, INPUT);
    pinMode(dtmf_pinQ4, INPUT);

    pinMode(digital_out_1, OUTPUT);

    Wire.begin();
    configure_mcp23017(); // IO Extender configuration

    Serial.begin(9600);
    Serial.println("hymRC Repeater Contoller (TA7W/OH2UDS-2021)");
    interrupts();


}

void loop() {

  unsigned long current_time = millis();




  while (1)
  {
      Wire.beginTransmission(MCP23017_ADDR);
      Wire.write(0x12); // address port A
      Wire.write(0x00);  // value to send
      Wire.endTransmission();

      Wire.beginTransmission(MCP23017_ADDR);
      Wire.write(0x13); // address port B
      Wire.write(0x00);  // value to send
      Wire.endTransmission();


      delay(500);
      Wire.beginTransmission(MCP23017_ADDR);
      Wire.write(0x12); // address port A
      Wire.write(0xFF);  // value to send
      Wire.endTransmission();

      Wire.beginTransmission(MCP23017_ADDR);
      Wire.write(0x13); // address port B
      Wire.write(0xFF);  // value to send
      Wire.endTransmission();
      delay(500);
      Serial.print(".");

  }






  if (( current_time >= timer_stop_tx ) && ( tx_state == true )) 
  {
    Serial.println("wait RX Tail"); 
    change_ptt_state(false);
    tx_state = false;
  }

  if (execute_cmd == true)
  {
    if (check_password() == true)
    {
      Serial.println("Password OK");
      exec_command();
    }
    else
    {
      Serial.println("Wrong password");
    }
  execute_cmd = false;
  }


}


/*
 * Initialize repeater configuration woth default paramaters if no data in EEPROM,
 * If data in EEPROM then use that information for initialization
 * input: 
 * configuration : pointer to repeater configuration to be updated
 * 
 * output: 
 * -
 */
void init_configuration(Repeater_configutarion_t* config)
{
  // TODO: read default values from EEPROM
  config->state = REPEATER_ON; 
  config->beaconmode = BEACON_NONE;
  config->tx_tail_s = txtail_ms;
  config->user_password = 0x1461;
  config->admin_password = 0x0666;
  
}


/*
 * DTMF Read on STD FAILING Edge Interrupt Function
 * D2 port is the interrupt pin connected to StD output of MT3170/8870 which goes high/low after a DTMF reception
 * D4 is MT3170/8870 Q1
 * D5 is MT3170/8870 Q2
 * D6 is MT3170/8870 Q3
 * D7 is MT3170/8870 Q4
 */
void dtmf_interrupt() {
  uint8_t dtmf_digit = (PIND & 0x00F0) >> 4;
  if ((dtmf_digit != 12) && (dtmf_cnt == 0)) return;
  if ( dtmf_digit == 12) dtmf_cnt = 0; //# digit restarts the sequence
  if ((dtmf_digit == 11) && (dtmf_cnt >= 7)) execute_cmd = true;
  dtmf_command[dtmf_cnt] = dtmf_digit;
  dtmf_cnt++;
  //Serial.println(millis());
  timer_command_timeout = millis() + command_timeout_ms;
  timer_dtmf_timeout = millis() + dtmf_timeout_ms;
}


/*
 * Squelch State Change Interrupt Function
 */
void squelch_interrupt() {
  uint8_t sql_state = digitalRead(squelch_in_pin);
  //Serial.println(sql_state);
  if (sql_state == SQL_OPEN_LEVEL)
  {
    Serial.println("SQL ON");
    change_ptt_state(true);
    timer_stop_tx = millis() + txtimemout_timer_ms;
    tx_state = true;
  }
  else
  {
    timer_stop_tx = millis() + txtail_ms;
    //noInterrupts();
    //TCNT1 = 15624;   // preload timer
    //TIMSK1 |= (1 << TOIE1); //Enable Timer Overflow Interrupt
    //interrupts();
  }
  
}


/*
ISR(TIMER1_OVF_vect)        // interrupt service routine 
{
	//TCNT1 = 15624;   // preload timer
  
	interrupts++;
	if ((interrupts >= repeater_configuration.tx_tail_s) && digitalRead(squelch_in_pin))
  {
    digitalWrite(ptt_pin, LOW);
    TIMSK1 &= ~(1 << TOIE1);
    interrupts = 0;
  }
}

*/


/*
 * Check the password that is in dtmf_command[1][2][3][4] bytes
 * and compare with repeater configuration user or admin password
 * return:
 * true if passwords match
 */

bool check_password()
{
  uint16_t passwd = (dtmf_command[1] << 12) + (dtmf_command[2] << 8) + (dtmf_command[3] << 4) + dtmf_command[4];
  if ((passwd == repeater_configuration.admin_password) || (passwd == repeater_configuration.user_password)) return true;
  return false;
}


/*
 * Executes the command stored if dtmf_command[5][6]
 */

void exec_command()
{
  uint8_t repeater_command  = (dtmf_command[5] << 4) + dtmf_command[6];
  bool cmd_valid = true;
  switch(repeater_command)
  {
    case COMMAND_REPEATER_ON:
      repeater_configuration.state = REPEATER_ON;
      Serial.println("REPEATER ON");
      break;
    case COMMAND_REPEATER_OFF:
      repeater_configuration.state = REPEATER_OFF;
      Serial.println("REPEATER OFF");
      break;
    case COMMAND_BEACON_ON:
     Serial.println("BEACON ON");
      repeater_configuration.beaconmode = BEACON_MORSE;
      break;
    case COMMAND_BEACON_OFF:
      Serial.println("BEACON OFF");
      repeater_configuration.beaconmode = BEACON_NONE;
      break;
    case COMMAND_DIGITAL1_ON:
      Serial.println("FAN ON");
      digitalWrite(digital_out_1, HIGH);
      break;
    case COMMAND_DIGITAL1_OFF:
      Serial.println("FAN OFF");
      digitalWrite(digital_out_1, LOW);
      break;

    default:
      //Invalid Command
      cmd_valid = false;
  }

  if (cmd_valid)
  {
      //TODO : respond with no_error tone
  }
  else
  {
      //TODO : respond with error tone
  }
}



/*
 * Changes PTT pin state using the ON/OFF hig/low level definitions and port definitions
 * Also checks repeater state for triggering PTT_ON
 */

void change_ptt_state(bool state)
{
if (state)
{
  if (repeater_configuration.state == REPEATER_ON)
  {
    digitalWrite(ptt_pin, HIGH);
    Serial.println("PTT On");
  }
  else
  {
    Serial.println("REPEATER is off... no TX");
  }
}
else
{
  digitalWrite(ptt_pin, LOW);
  Serial.println("PTT Off");
}
}


/*
 * register_write(register, value) is used for writing value to
 * a register using I2C wire bus
 * 
 */

void register_write(uint8_t register_address, uint8_t register_value )
{
  Wire.beginTransmission(MCP23017_ADDR);
  Wire.write(register_address);
  Wire.write(register_value);
  Wire.endTransmission();
}

/*
 * Initial configuration of MCP23017 16 Bit I/O Extender
 * I2C communication address is set in header as 0x20 MCP23017_ADDR
 * 
 * A0
 * A1
 * A2
 * A3
 * A4
 * A5
 * A6
 * A7
 * A8
 * 
 * B0 MT8870 Q1       (input) Interrupt On Pin
 * B1 MT8870 Q2       (input) Interrupt On Pin
 * B2 MT8870 Q3       (input) Interrupt On Pin
 * B3 MT8870 Q4       (input) Interrupt On Pin
 * B4 MT8870 StD      (input) Interrupt On Change 
 * B5 General Purpose (input) No Interrupt
 * B6 General Purpose (input) No Interrupt
 * B7 General Purpose (input) No Interrupt
 * 
 * INTA -> Pin 2 of MCU (INT0)
 * INTB -> Pin 3 of MCU (INT1)
 * 
 */

void configure_mcp23017()
{
                                    // Configure Port_A
                                    // (Register 0x00 : IODIRA)   Direction Configuration
  register_write(0x00,0xFF);        //                            set all of port A to inputs
                                    // (Register 0x02 : IPOLA)    Input Polarity
  register_write(0x02,0x00);        //                            All pins reflect the same logic state (0)
                                    // (Register 0x04 : GPINTENA) Interrupt On Change Control
  register_write(0x04,0b00001000);  //                            Only StD pin of MT8870 will have on-change int
                                    // (Register 0x06 : DEFVALA)  Default Compare Interrupt
  register_write(0x06,0b11110000);  //                            Q1-Q4 pins of MT8870 will have default-state of 1
                                    // (Register 0x06 : INTCONA)  Default Compare Interrupt
  register_write(0x08,0b11110000);  //                            Q1-Q4 pins of MT8870 will have default-compare int
                                    // (Register 0x0A : IOCONA)   Configuration Register 
  register_write(0x0A,0b10100010);  // bit-7 (1) BANK:   The registers associated with each port are separated into different banks.
                                    // bit-6 (0) MIRROR: The INT pins are not connected. INTA is PORTA and INTB is associated with PORTB
                                    // bit-5 (1) SEQOP:  Sequential operation disabled, address pointer does not increment.
                                    // bit-4 (0) DISSLW: Slew rate enabled
                                    // bit-3 (0) HAEN:   Disables the MCP23S17 address pins.
                                    // bit-2 (0) ODR:    Active driver output (INTPOL bit sets the polarity.)
                                    // bit-1 (1) INTPOL: Active-high
                                    // bit-0 (0) -

                                    // Configure Port_B
                                    // (Register 0x01 : IODIRB)   Direction Configuration
  register_write(0x01,0x00);        //                            set all of port B to outputs
                                    // (Register 0x03 : IPOLB)    Input Polarity
  register_write(0x03,0x00);        //                            All pins reflect the same logic state (0)
                                    // (Register 0x05 : GPINTENB) Interrupt On Change Control
  register_write(0x05,0b00001000);  //                            No pin will have on-change int
                                    // (Register 0x07 : DEFVALB)  Default Compare Interrupt
  register_write(0x07,0b00000000);  //                            All pins will have default-state of 0 (output pins)
                                    // (Register 0x09 : INTCONB)  Default Compare Interrupt
  register_write(0x09,0b00000000);  //                            No pins will have default-compare int (output pins)
                                    // (Register 0x0B : IOCONB)   Configuration Register 
  register_write(0x0B,0b10100010);  // bit-7 (1) BANK:   The registers associated with each port are separated into different banks.
                                    // bit-6 (0) MIRROR: The INT pins are not connected. INTA is PORTA and INTB is associated with PORTB
                                    // bit-5 (1) SEQOP:  Sequential operation disabled, address pointer does not increment.
                                    // bit-4 (0) DISSLW: Slew rate enabled
                                    // bit-3 (0) HAEN:   Disables the MCP23S17 address pins.
                                    // bit-2 (0) ODR:    Active driver output (INTPOL bit sets the polarity.)
                                    // bit-1 (1) INTPOL: Active-high
                                    // bit-0 (0) -
}

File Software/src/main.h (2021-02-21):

#ifndef MAIN_H_
#define MAIN_H_


#define MCP23017_ADDR 0x20

/* Function patamerters */
#define txtail_ms 1000       // Kuyruk suresi (milisaniye)
#define txtimemout_timer_ms 12000  // TOT Timeout Timer 120 saniye (2 dakika)
#define command_timeout_ms 10000 // Toplam komut gonderme suresi (milisaniye)
#define dtmf_timeout_ms 3000     // DTMF kodlari arasindaki maksimum sure (milisaniye)

#define SQL_OPEN_LEVEL 0


/* Pin Definition */
#define dtmf_pinSTD    2
#define squelch_in_pin 3 // Squelch Giris Pini D3
#define dtmf_pinQ1     4
#define dtmf_pinQ2     5
#define dtmf_pinQ3     6
#define dtmf_pinQ4     7
#define ptt_pin        8 // TX tarafinin PTT baglantisi B0
#define digital_out_1  9 // FAN Kontrolu vb.

/* Type Definitions */
typedef enum
{
    REPEATER_OFF = 0x00,
    REPEATER_ON  = 0x01
} Repeater_state_t;

typedef enum
{
    BEACON_NONE  = 0x00,
    BEACON_MORSE = 0x01,
    BEACON_AX25  = 0x02,
    BEACON_BOTH  = 0x03
} Beaconmode_t;

typedef enum
{
    COMMAND_REPEATER_ON         = 0x11,
    COMMAND_REPEATER_OFF        = 0x12,
    COMMAND_DIGITAL1_ON         = 0x21,
    COMMAND_DIGITAL1_OFF        = 0x22,
    COMMAND_DIGITAL2_ON         = 0x23,
    COMMAND_DIGITAL2_OFF        = 0x24,
    COMMAND_DIGITAL3_ON         = 0x25,
    COMMAND_DIGITAL3_OFF        = 0x26,
    COMMAND_BEACON_ON           = 0x31,
    COMMAND_BEACON_OFF          = 0x32,
    COMMAND_INITIALIZE          = 0x44,
    COMMAND_REPORT_STATUS       = 0x50,
    COMMAND_GET_READ_BATTERY    = 0x51,
    COMMAND_GET_TEMPERATURE     = 0x52,
    COMMAND_GET_ANALOG          = 0x53,
    COMMAND_SET_TAIL_TIME       = 0x70,
    COMMAND_SET_USER_PASS       = 0x71,
    COMMAND_SET_ADMIN_PASS      = 0x72
} Dtmf_commands_t;


typedef struct 
{
    Repeater_state_t    state;
    uint16_t            tx_tail_s;
    uint16_t             user_password;
    uint16_t             admin_password;
    char                call_sign[6];
    uint8_t             inhibit_tx;
    Beaconmode_t        beaconmode;

} Repeater_configutarion_t;

typedef struct 
{
    float               aku_voltaj;
    uint8_t             fan_durum;

} Beacon_meassage_t;


void dtmf_interrupt();
void squelch_interrupt();
void init_configuration(Repeater_configutarion_t* config);
bool check_password();
void exec_command();
void change_ptt_state(bool state);
void configure_mcp23017();

#endif /* MAIN_H_ */

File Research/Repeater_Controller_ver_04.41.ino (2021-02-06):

#include <Event.h>
#include <Timer.h>


// ==========================================================================
//
//        Repeater software for ARDUINO UNO
//       Magic Valley Amateur Radio Club Twin Falls Idaho
//       version 4.2 dated April 10, 2015 tested and debugged dwe
//        version 4.4 dated Apr 16, 2016  totally tested and debugged.  dwe
//         version 4.41 dated Sep 12, 2012 improved notes and comments.  dwe
//===========================================================================
// "Repeater logic" by Daniel Forsstrom - SM4XAS- www.forsstrommusic.se
// NOTE: I used only Daniel's Morse Code encoder functions - The repeater logic in mine. Dean, KI7CC
// ==========================================================================
//===========================================================================
/*  DEAN ETHERINGTON Notes:
 1.The COS "receiver squelch" is the main control trigger input signal.   When the COS has not been active
 for 15 or more seconds, and then goes ACTIVE,  the controller will "key up" PTT, and send the Call Sign.
 2. After COS ACTIVE, the cwid timer starts timing for "CWID TIM" seconds. After CWID timeout, the repeater will send your
 Call Sign,  and reset the CWID Timer.
 3. If  the COS signal remains active  for more than the "T_out" seconds, a timeout will occour that will shut
 down the PTT signnal and termininate transmissions until after the COS signal goes inactive again. Any CWID event during a "Timeout"
 event will transmit your Call Sign (800 HZ tone) and also  "TIME OUT" in Morse Code(1000 HZ tone).
 4. Aditional external audio circuits must be added to mix the CWID Morse Code out of PIN 5,
 and the receiver's audio,  before passing the audio to the transmitter.
 5. The PTT out signal should have a transister buffer to protect the microprocessor output  pin.
 If the PTT drives a relay - you also need a protection diode for reverse emf voltages.
 The  PTT signal into the transmitter is usually active LOW.  Here I would use a transistor (or FET)
 to pull the PTT line LOW.
 6.  If your radio's output signals for COS and TPL are greater than 5 VDC, use diodes to protect the Arduino inputs.
 Connect the negative end of a diode to the Radio's output signal, and the positive end of the diode to the
 Arduino input pin.  The Radio's output signals will then pull the Arduino inputs "LOW" (when the signal is  "low")
 to interface with the controller.
 The diodes will limit the input signals to the 5 VDC "input pull up" value of the arduino input pin.

 NOTEs:
 1.   If your receiver does not decode TonePL (CTCSS sub audible tone), leave pin D6 unconnected and leave int TPLactive = 1.
 1a.  Some receivers combine COS and TPL into one signal.
      Connect the combined COS/TPL signal to the "COSin" pin. The correct CTCSS (TPL) settings must be programmed into your receiver.
      Do a Google Search for "CTCSS" to obtain a defination. CTCSS stands for "Continuous Tone Coded Squelch System".
 2.   Connect the UNO digital pin 2 to the MT8870D's Pin 15 ("StD").   This is the INTERRUPT Input Signal for the DTMF functions.
 3.   Use a 1 ampere MOSFET to dirve the fan output (OPEN DRAIN) from pin 12.
 4.   Enter your repeater's user variables below, starting with MorseWPM   !!!!!!!!!!!!!!!!!!!!!!!!!!!!!!!!!!!!!!!!!!!!!!!!!!!!!!!!!!!!!!
 5.   The DTMF Commands (RPTR on/off & TPLR on/off) are stored in the EEPROM, and read out at each power up, or Arduino RESET, during the SetUp function.
      a.Operaror_code+00 turns off the repeater (i.e.19000 until you  change the Operator_Code.)
      b.Operaror_code+01 turns on the repeater (i.e.19001 until you  change the Operator_Code.)
      c.Operatorode+02 turns Off the TPL (CTCSS) - Tone not required for access to the Repeater.(i.e.19002 until you  change the Operator_Code.)
      d.Operatorode+03 turns ON the TPL (CTCSS) Required- Tone is required for access to the Repeater.(i.e.19003 until you  change the Operator_Code.)
 6.  Importing the Libraries:  "iimer.h" search Arduino for "Master-Timer library",  "EEPROMex.h" search for EEPROMex library.   The Arduino I.D.E. help files will istruct you about importing libraries.
    //                        https://github.com/JChristensen/Timer                  // http://github.com/thijse/Arduino-Libraries/tree/master/EEPROMEx
 7.  The "Serial.print();" commands are included in the sketch for debugging use.
 //================================================================================================================================================================
//!!!!!!!!!!!!!!!!!!!!!! you MUST connect the UNO digital pin 2 (interrupt input) to the MT8870D PIN 15 "StD"  !!!!!!!!!!!!!!!!!!!!!!!!!!!!!!!!!!!!!!!!!!!!!!!!!!!!!!
//================================================================================================================================================================

 */


// Setup and configurational data..
// ----------------------------------------------------------------------------------------
#include "Timer.h"
#include <EEPROMex.h> //allows reading and writing nearly all types of variables to/from EEPROM.

Timer t;                //the main timer. also see onesec().
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

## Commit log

2021-01-28 ilk pin atamalari
2021-01-28 pin atamalari
2021-01-28 pin tanimlari
2021-02-06 MT8870
    MT8870 is same as KT3170...
    Mine was MT3170D..... Which is not 18 pin, but 20 pin SOIC.,,,
    Which has slight different pinout which you can find in MT8870D datasheet
2021-02-06 pin corrections
2021-02-06 3170 Pin secenekleri
2021-02-06 Sample project added
2021-02-21 Draft Schematic
    [hymRC.kicad_pcb, hymRC.sch]
2021-03-13 huda calisma
    [hymRC.kicad_pcb, hymRC.sch]
2021-03-17 audio buffers added
    [hymRC.sch]
2021-03-17 opkuplers added.. both negative and positive triggered
    [hymRC.sch]
2021-03-18 main component footprints and links added to library
    [hymRC.sch]
2021-03-18 resistors changed to smd 0805
    [hymRC.sch]
2021-03-18 capcsitors are 0805 now
    [hymRC.sch]
2021-03-18 DRC checks resolved
    [hymRC.kicad_pcb, hymRC.sch]
2021-03-18 initial PCB
    [Poti SMD 5k Bi Technologies 23AR5KLFTR.stp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]
2021-04-04 Audio section completed
    [hymRC.kicad_pcb, hymRC.sch]
2021-04-05 all connected somehow
    [hymRC.kicad_pcb, hymRC.sch]
2021-04-05 digitals connected
    [hymRC.kicad_pcb, hymRC.sch]
2021-04-05 routing finished
    [hymRC.kicad_pcb, hymRC.sch]
2021-04-05 3d finished
    [hymRC.kicad_pcb]
2021-04-05 3d wrl added
    [EE2-3TNUH-L--3DModel-STEP-56544.STEP]
2021-04-05 all done
    [hymRC.kicad_pcb]
2021-04-05 BOM list
    [hymRC.csv]
2021-04-05 Titles added
    [hymRC-B_Cu.gbr, hymRC-B_Mask.gbr, hymRC-B_Paste.gbr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]
2021-04-05 titles added to PCBs
2021-04-06 SOIC-20 footprint squeezed
    [hymRC-B_Cu.gbr, hymRC-B_Mask.gbr, hymRC-B_Paste.gbr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]
2021-05-10 PCBs arrived
